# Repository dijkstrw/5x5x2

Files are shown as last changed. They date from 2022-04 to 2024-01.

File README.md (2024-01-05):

5x5x2 aka Orochi!
=================

This is a 5x5 Cherry mx matrix with hotswap Kailh sockets based my own
firmware for the STM32F1 with libopencm3. The project contains
firmware, schematics and a board layout in kicad.

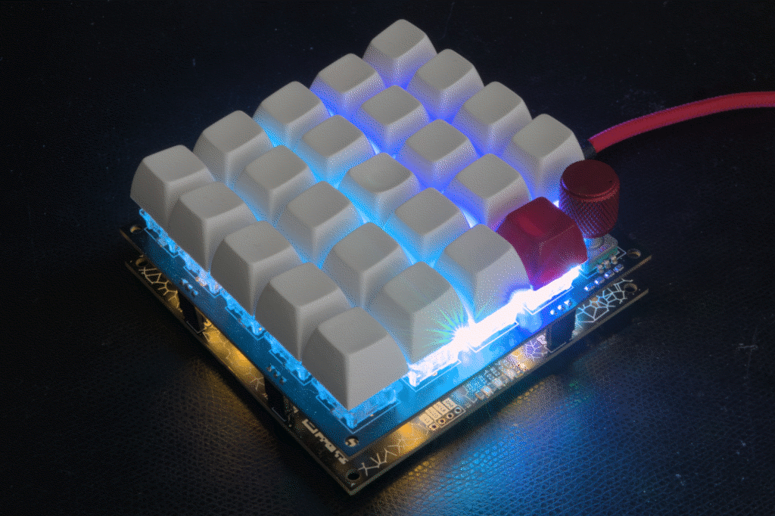
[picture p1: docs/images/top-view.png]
Board Front Picture


Features you expect given the above picture:
- bios boot and nkro keyboards, using usb keyboard scancodes
- system and consumer codes
- mouse events
- usb serial interface for configuration
- 8 sk68xx background leds on the bottom board
- 25 sk68xx underglow leds on the top board
- rotary encoder

Advanced features:
- adjustable speed macrokeys to e.g. emit passwords
- all leds individually addressable, colorchord support
- leds can light on e.g. volume or desktop changes
- configuration can be adjusted and flashed in userflash
- and an automouse that can simulate fast clicking

More pictures of the board and the development dongle are
[here](docs/IMAGES.md). If you want to build this yourself see
[building](docs/BUILDING.md). Interactive bom is
[here](https://glcdn.githack.com/dijkstrw/5x5x2/-/raw/30abe2597a5d5bfca67bad37a444652a956d1f03/schematic/bom/ibom.html).

Default firmware / my usecase
-----------------------------

This is my macropad; it contains three layers:

- X workspace layer, select workspace number, move about in VLC, start
  apps, compose key, quick jump to password layer and a number of app
  starting keys. Rotary dial controls system volume. Rotary press
  mutes/unmutes.

  Rgbleds show sound volume, current workspace / screen and active
  layer.

- numeric keypad, for when tkl is not enough

- macrokeys layer

Features
========

Keyboards
---------

The board provides 3 types of keyboards via different usb
endpoints.

1. The first is the usb standard bios keyboard definition, which
   allows the keyboard also to emit key codes to hosts with limited
   usb hid support. (This used to be the case in <2015 style bioses,
   hence the name.)

2. The second keyboard is a n-key-rollover, which exposes a keyboard
   that allows 224 usb keyboard scancodes to be pressed
   simultaneously. Also, because we do not need to adhere to the bios
   boot standard, this endpoint's interval can set much lower = it
   types much faster.

3. The third keyboard can emit so called consumer and system
   codes. Example consumer key codes are PLAY, PAUSE, but also MARK,
   CLEARMARK, REPEATFROMMARK. So everything the typical multimedia
   keys emit and then some.

Mouse
-----

Operate the rodent from your keyboard! There is support for x, y, 5
buttons and a vertical and horizontal scrollwheel action.

Serial
------

The board exposes a serial port for logging and
configuration. Configuration is done using commands, with these
general rules:

- Commands with lowercase letters request configuration information

- Commands with capital letters set configuration

- Arguments often are two hexadecimal digits long; e.g. ``00``,
  ``12``, ``fa``. If more digits are required, this is denoted in the
  argument specification by a colon, like so ``<argument:4>``.

The available commands are:

    ?  - show a terse description of available commands.

    i  - show usb info strings; contains the git-describe tag of the
         current firmware.

    d  - dump configuration of a named subsystem, see below.
    dg - dump the keymap light group
    dk - dump the keymap
    dp - dump the palette
    dr - dump the rotary configuration

    B  - set the bottom set of 8 leds (backlight) to custom rgb values.
         Takes a RGB argument of the form <rgb:6> times 8 for all leds.

    C  - set the top set of 25 leds (frontlight) to custom rgb values.
         Takes a RGB argument of the form <rgb:6> times 25 for all leds.

    D  - tell keyboard about an event that can be translated into a rgb
         light event, see below.
    DD - <screen><display> set current desktop display
    DM - <mute>            set sound output mute status
    DR - <mute>            set sound input/record mute
    DV - <volume:4>        set sound volume
         See config directory for a program that emits these events to the
         keyboard.

    G  - set light map for a key, takes argument of the form
         <layer><row><column><value>

    I  - set the rgb light intensity.

    K  - redefine a key in the keymap, takes argument of the form
         <layer><row><column><type><arg1><arg2><arg3>

    A  - clear all macro keys.

    M  - define one macro key, takes an argument of the form
         <number><oftenusedstring>. The number is a two hexdigits, the
         string can be upto 32 7-bit ascii chars long and is terminated
         with a newline.

    N  - set keyboard mode to <argument>; 00 for bios and 01 for nkro.
         Default is bios.

    P  - set palette color, takes arguments
         <number><hue:4><saturation><value>

    R  - redefine the rotary command, takes a argument of
         the form <layer><direction><type><arg1><arg2><arg3>

    L  - load configuration from flash

    S  - save configuration to flash

    Z  - clear the configration flash, revert to "factory" keymap at
         next powerup.

Command interpretation starts after receiving a newline.

Light events
------------

The keyboard will show desktop events as rgbled changes. This works in
a number of steps:

- There is a host program that connects to the serial port, monitors
  sound and workspace changes and communicates that back to the
  keyboard. The program can be found in
  [susanoo.py](config/susanoo.py). Note that workspace changes sent
  via a fifo using the desktop manager and
  [configuration](config/keys_orochi.lua).

- Incoming events are mapped to be shown on particular leds using the
  lightmap command.

- The events all have their own displays:

         B - backlight    - slow rainbow easing
         D - desktop      - desktop display mapped over palette
         L - layer        - layer mapped over palette
         m - macro        - if macro active, else backlight
         M - sound mute   - different colors for mute status
         V - volume       - volume mapped to color

Palette
-------

Colors in easings are assigned using a color index in the palette. The
default palette strives for a selection of colors that are visually
distinct from another.

The rotary action forward, backward and backlight colors have fixed
indexes, and can be set by adjusting their assigned palette colors.

Automouse
---------

Automouse is a mouse clicker, with optional speed setting and wiggle
amounts. This allows you to click real fast, and wiggle the mouse
while using your hands for something else.

Macros
------

Macros set via serial are lost at power off unless the configuration
is written to flash. Loading from flash happens automatically at
powerup.

The strings that you provide via serial need to be translated into usb
keycodes, so currently only 7-bit ascii strings are supported.

Setting macros via the shell is easy:

    echo -e "\nM01Nevergonnagiveyouup!\n" > /dev/ttyACM0

Or see [set_macro.sh](util/set_macro.sh).

Notes:

- The initial newline is a trick to make sure our M will be considered
  the start of a command, no matter what has been put to the serial
  before by you, some driver or the os.
- This particular example defines the macro for macro key number 1.
- You need to have a macro key 1 in your keymap, otherwise you have
  nothing to trigger the macro.
- There is intentionally no way to display stored macros.

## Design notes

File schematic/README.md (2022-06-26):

Other keyboard projects of interest:

- foostan: corne / crkb: the first time I saw sk6812 in mini-e
  variant. 
  
  https://github.com/foostan/kbd
  https://github.com/foostan/crkbd
  
  MIT license, parts reused:
  - Source of YS-SK6812-MINI-E schematic symbol, and 3d step model.

- KarlK90: Yaemk: indication that usb-c receptacle is usable without
  usb power negotiation.
  
  https://github.com/KarlK90/yaemk-split-kb
  
  GPLv3, used for inspiration only.

- Stefan Hamminga: sk6812mini model that models the underside of the
  package best.

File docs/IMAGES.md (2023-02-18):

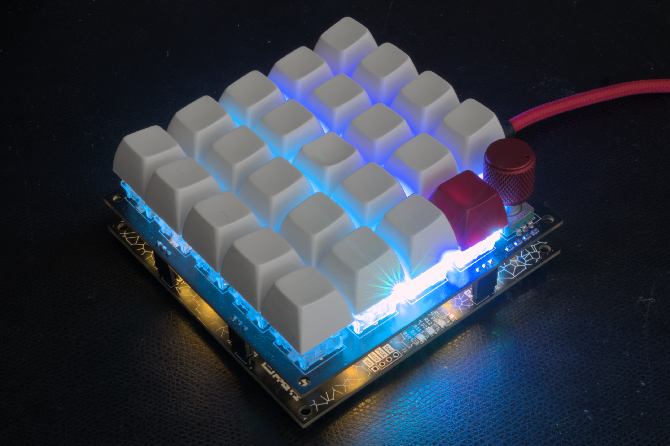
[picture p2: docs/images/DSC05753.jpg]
Orochi

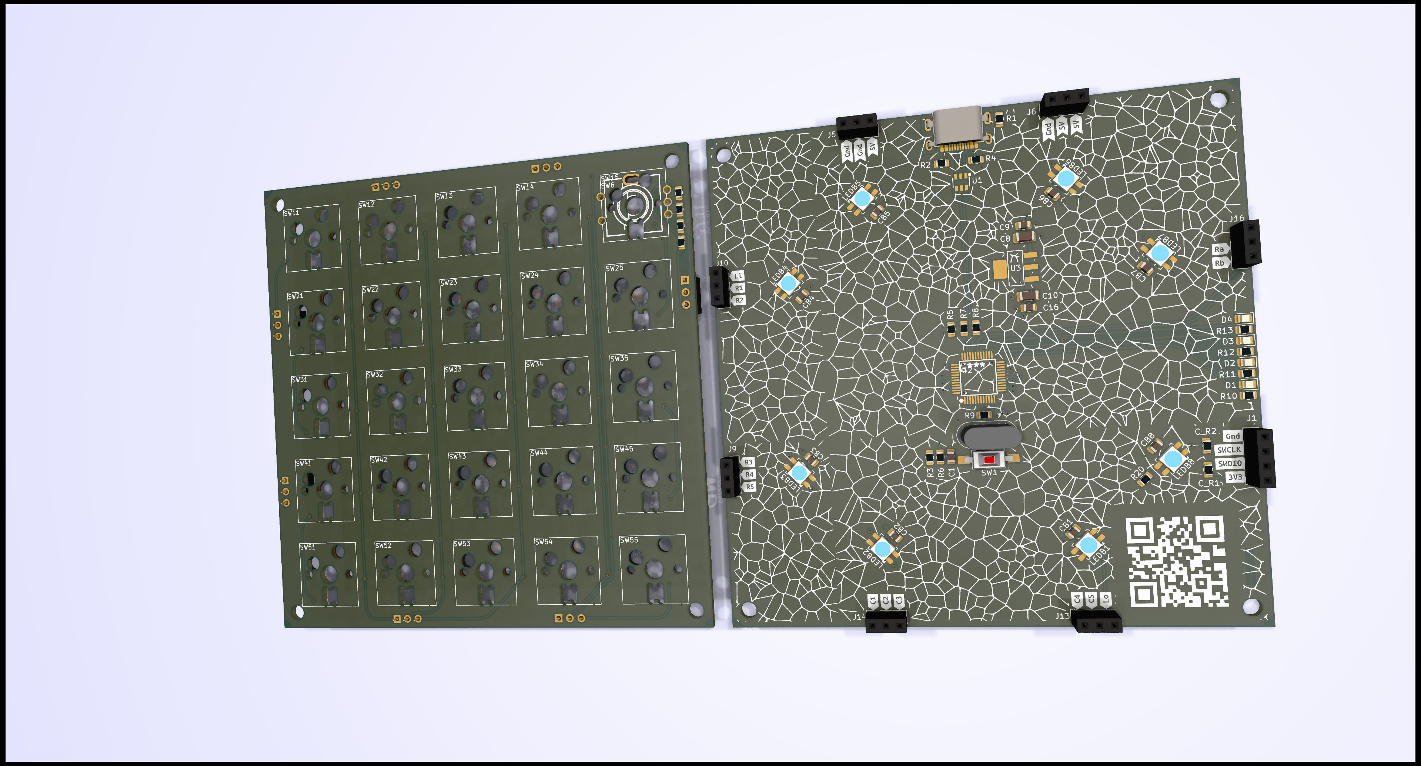
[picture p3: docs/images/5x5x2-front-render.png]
PCB front render

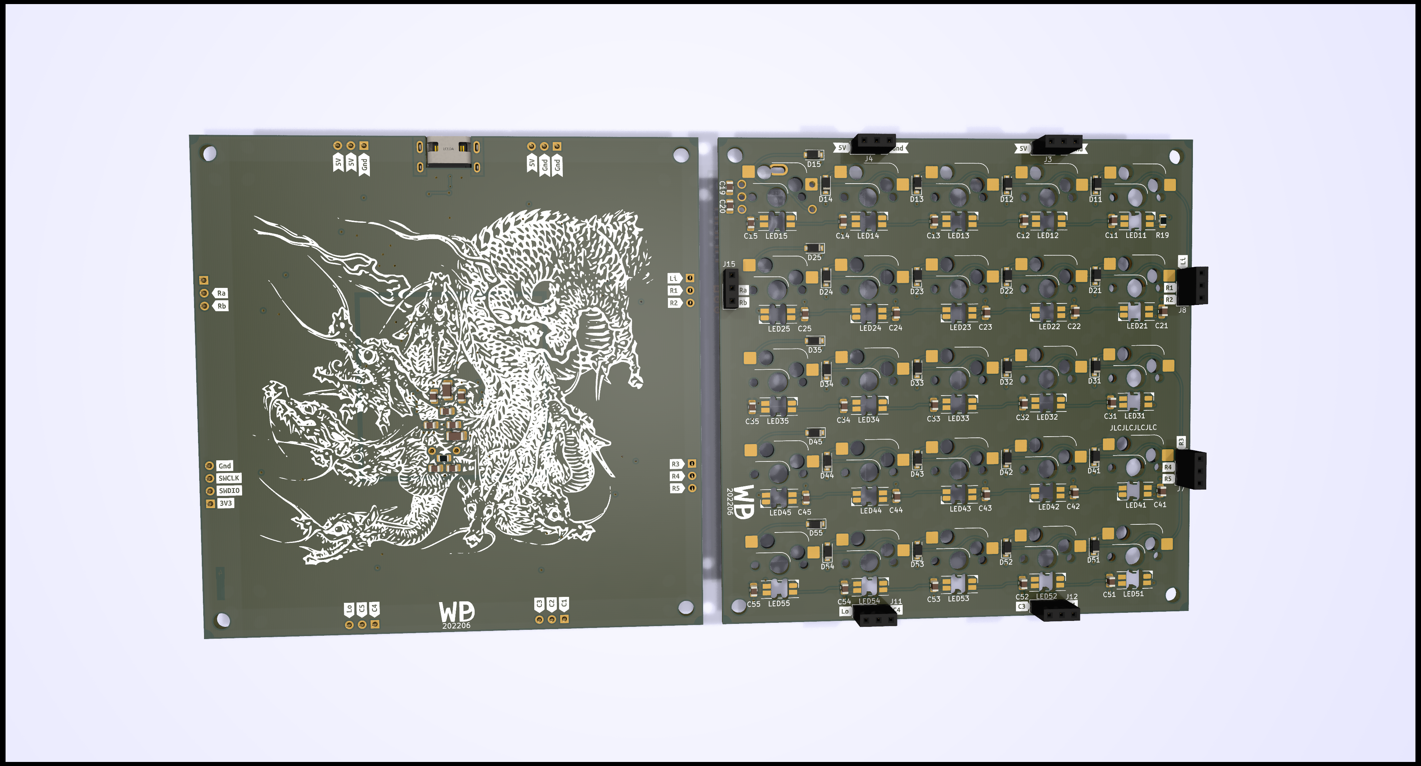
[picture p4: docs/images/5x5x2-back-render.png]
PCB back render

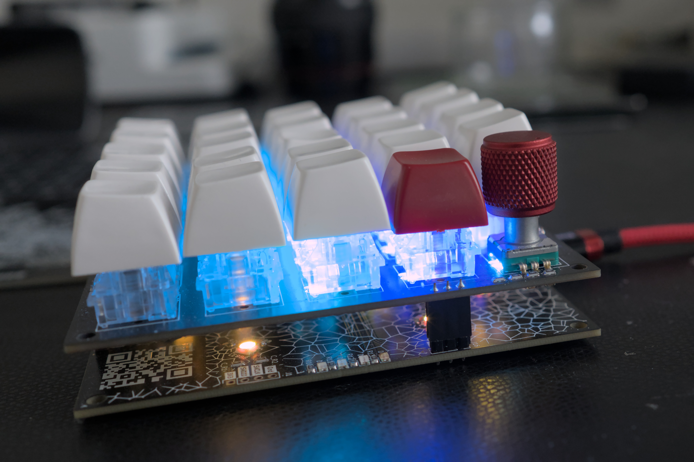
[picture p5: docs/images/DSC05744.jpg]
Side view

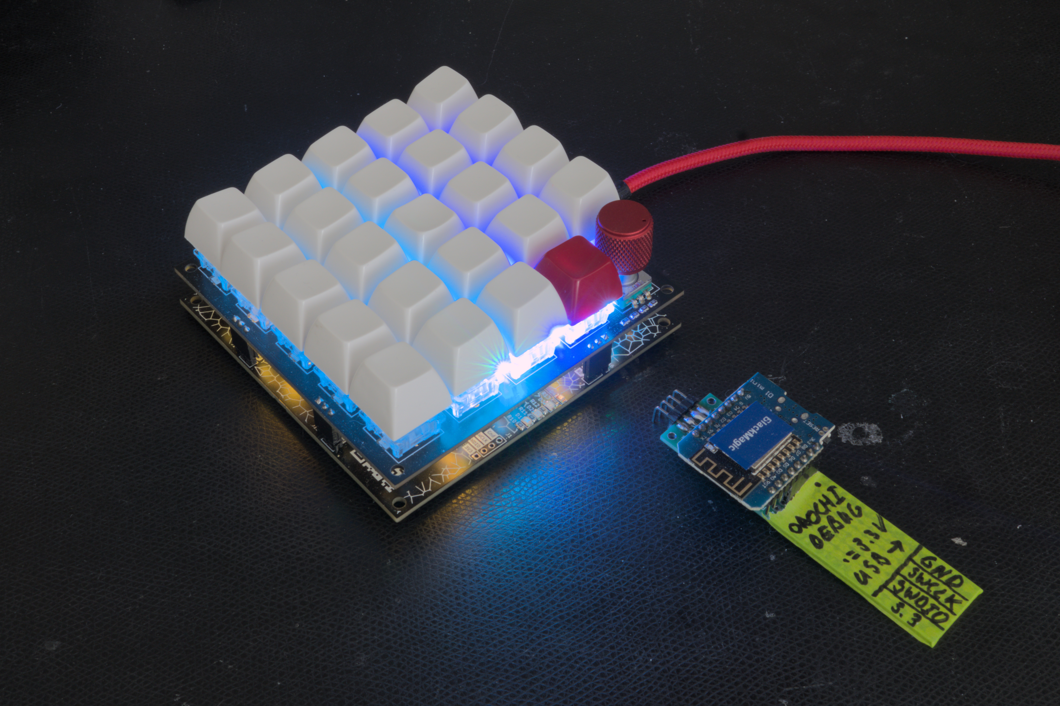
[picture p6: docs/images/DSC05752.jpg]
Development board


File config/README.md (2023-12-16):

Host configuration
==================

Orochi can be updated from the host using
[susanoo.py](susanoo.py). This program creates a fifo and a unix
domain socket that can be used to communicate with the keyboard.

- fifo: can be used by shell commands to push some state to the
  keyboard

- socket: can be used i.e. by socat, to communicate via terminal with
  the keyboard, even while multiple other updaters are active.

Susanoo also connects to pulseaudio to communicate volume and mute
status to the keyboard.

Desktop state (what desktop a screen is on) can be communicated using
[keys_orochi.lua](keys_orochi.lua), when using
[awesomewm](https://awesomewm.org/). This make it so that any desktop
key press on the keyboard will change all desktops for all connected
monitors. I like to use this to have a desktop for mail, a desktop for
a coding problem, and a few more for other side avenues that can pop
up while working on something. Desktop changes in awesome are
communicated back to the keyboard, and cause the keyboard two top rows
to light in the color of the active desktop.

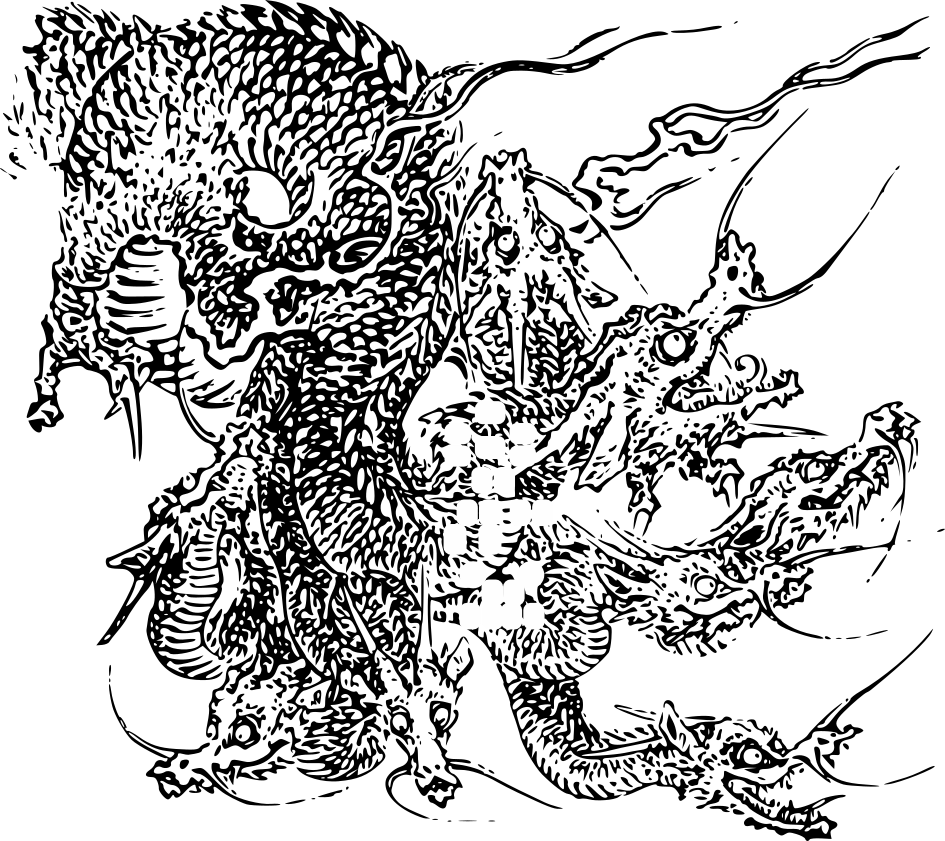
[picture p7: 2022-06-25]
schematic/images/orochi_board.png

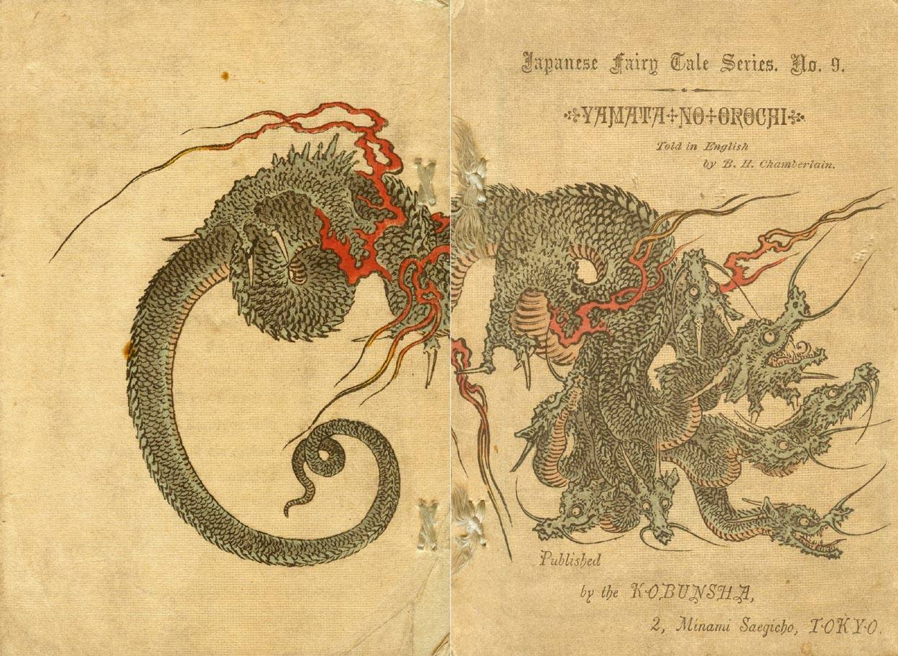
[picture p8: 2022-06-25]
schematic/images/orochi.jpg

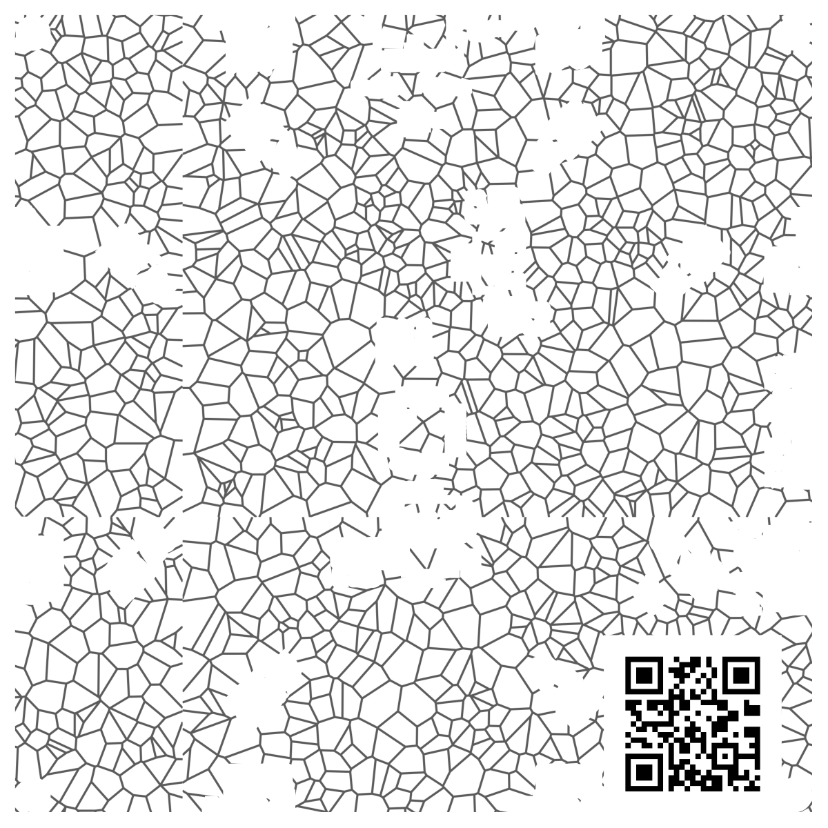
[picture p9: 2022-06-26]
schematic/images/sun.png

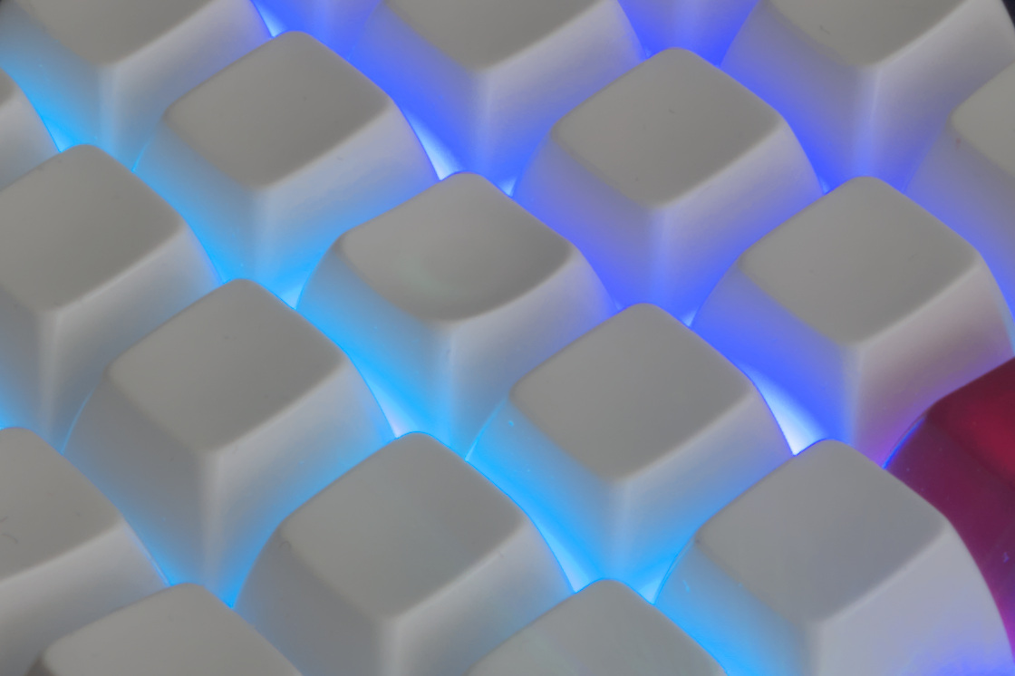
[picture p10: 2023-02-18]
docs/images/keys.jpg

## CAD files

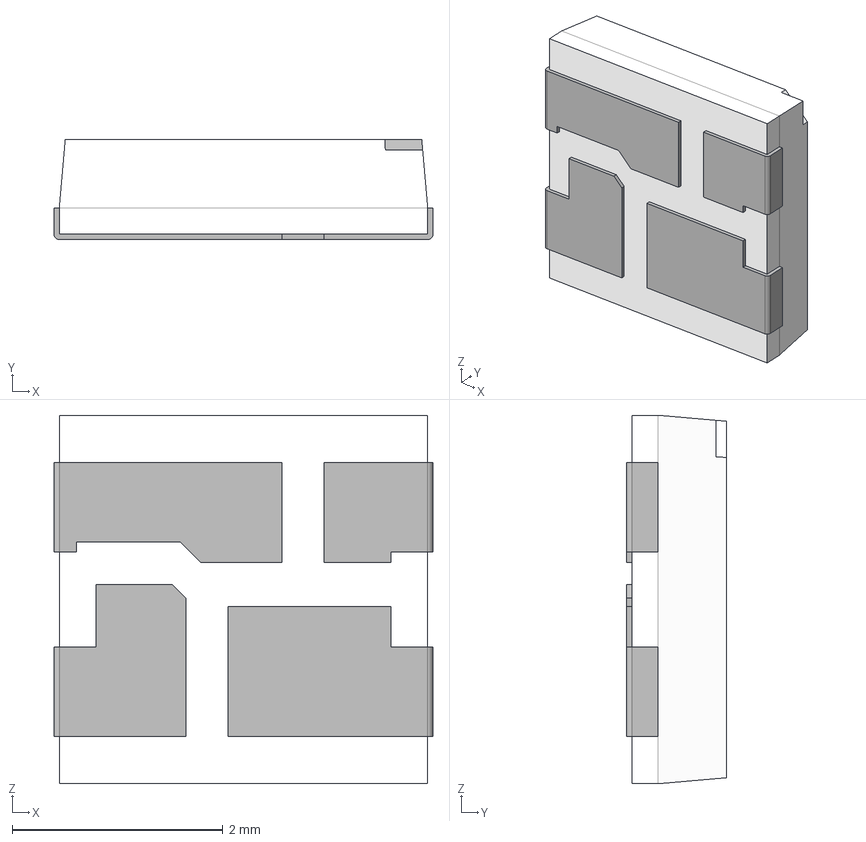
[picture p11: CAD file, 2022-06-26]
schematic/3dmodels/SK6812_Mini.step
3.60 x 0.95 x 3.50 mm
SK6812_Mini
SK6812_Mini004
SK6812_Mini003
SK6812_Mini005
SK6812_Mini002
SK6812_Mini001

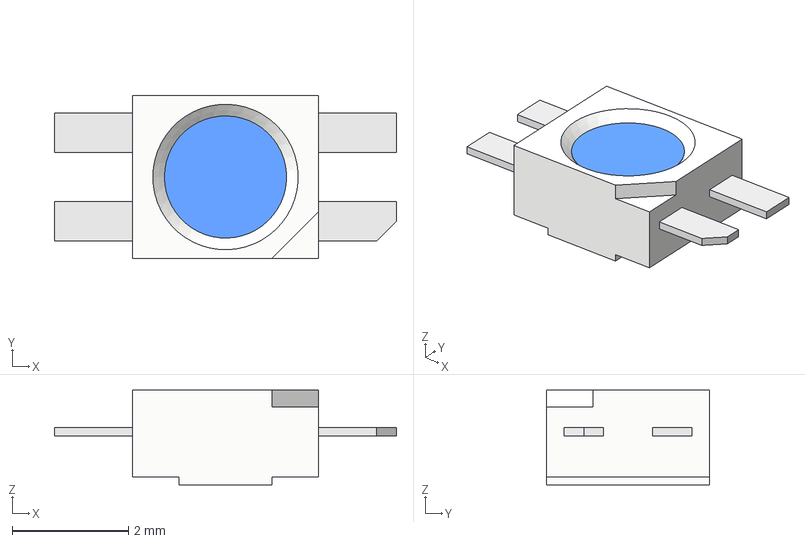
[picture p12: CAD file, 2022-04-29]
schematic/3dmodels/YS-SK6812MINI-E.step
5.88 x 2.80 x 1.63 mm

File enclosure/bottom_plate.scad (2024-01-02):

include <dimension.scad>;
include <plate.scad>;

if (PROJECTION) {
  projection(cut=true)
    bottom_plate();
 } else {
  bottom_plate();
 }

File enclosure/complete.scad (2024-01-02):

include <dimension.scad>;
include <plate.scad>;

bottom_plate();
translate([0, 0, bottom_height/2 + second_height/2]) second_plate();
translate([0, 0, bottom_height/2 + second_height + third_height/2]) third_plate();
translate([0, 0, bottom_height/2 + second_height + third_height]) top_plate();

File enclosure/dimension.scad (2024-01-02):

/*
 * Dimension of the boards as a stack:
 *
 *      mx switch stem     +                     3.6 mm
 *      mx switch top    ╭---╮                   6.6 mm
 *      mx switch foot   |   |                   5.0 mm -╮
 *             top pcb ╦═╪═══╪═══════════════╦   1.6 mm  |
 *                     ║                     ║   5.9 mm  | 15.1 mm
 *           lower pcb ╩═╪═════════════════╪═╩   1.6 mm  |
 *      solder fillets                           1.0 mm -╯
 *
 * The enclosure must enclose the pcb (100 x 100) and vertically from
 * the lower pcb solder fillets upto the mx switch foot. This is a
 * 15.1 mm span. To fixate the switches the top will be closed by a
 * metal plate with mx sized (13.8 x 13.8) holes in it. The plate is
 * 1.6mm thick, so the total vertical span to cover with the enclosure
 * material is 15.1 - 1.6 = 13.5 mm.
 *
 * The lower pcb has an usb c receptable, so room must be left for the
 * usb plug and overmoulding.
 *
 * PMMA layers can be bought in a variety of thicknesses, but we must
 * take care that in our stack-up the PMMA layer is supported by the
 * top or lower pcb to stay in place. This means that layer
 * transitions can only happen between 1.2 - 2.4 mm or 6.1 - 7.3 mm.
 *
 * Our 3mm screw inserts are 4.9mm high, so even with a 3mm baseplate,
 * our lower pcb will only start from 4.9mm -- this does mean that the
 * usb receptacle is at 4.9 + 0.8, and with usb overmoulding needing
 * 6.8mm, we need:
 *
 * - second layer = 1.9 screw insert +
 *                  0.8 middle of pcb +
 *                  6.8 / 2 usb plug size = 6.1mm
 * - third layer = 13.5 - 6.1             = 7.4mm
 *
 */

pcb_width = 100;             // width and depth of pcb to enclose
pcb_thickness = 1.6;         // thickness of the pcb
pcb_fillets = 1;             // max size of the fillets under pcb

wall_width = 3;              // width of the wall around the enclosure
screw_insert_size = 4.9;     // height of screw inserts

bottom_height = 3;           // height of bottom plate
second_height = 6.1;         // height of second plate
third_height = 13.5 - second_height;
top_height = 1.6;            // height of keys base plate

screw_hole_size = 3;         // hole size, m3 = 3mm
hole_offset = 3.5;           // offset of hole center to edge

usb_plug_height = 6.8;       // height of usb c plug overmoulding
usb_plug_width = 11;         // width of usb c plug overmoulding
usb_plug_depth = 24.3;       // depth of usb c plug, contact + overmoulding
usb_contact_height = 3;      // height of usb c contact

mx_plate_width = 13.8;
mx_edge_space = 5.5;
mx_inter_space = 5;

$fn = 50;                    // number of fragments in an arc

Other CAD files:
enclosure/plate.scad
enclosure/second_plate.scad
enclosure/third_plate.scad
enclosure/top_plate.scad

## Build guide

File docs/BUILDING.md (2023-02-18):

Building
========

The repo comes with a number of goodies to make developer life more
fun:

- docker definition for required toolchain
- docker/dev.sh to quickly and seamlessly issue commands in the toolchain container
- gdb-regview and .gdbinit to load pheriperal names into gdb
- use of blackmagic esp8266 to flash firmware via wifi

How to build the firmware
-------------------------

    git clone --recursive 5x5x2.git
    cd 5x5x2/docker
    docker build -t stm32-gcc .
    cd ..
    ./docker/dev.sh "make -C libopencm3 && make"

How to debug the firmware
-------------------------

I use an [esp8266](https://github.com/walmis/blackmagic-espidf)
programmed as a
[blackmagic](https://github.com/blacksphere/blackmagic) probe to
connect gdb via wifi to the target keyboard. The board has a 4-pin
SWIO/SWCLK .1'' header on the right lower side where the probe can be
attached.

```console
[dijkstra@mcu 5x5x2]$ ./docker/dev.sh 
root@df176a49d098:/mnt# make debug 
arm-none-eabi-gdb-py --command=.gdb_config
GNU gdb (GNU Arm Embedded Toolchain 10-2020-q4-major) 10.1.90.20201028-git
Copyright (C) 2020 Free Software Foundation, Inc.
License GPLv3+: GNU GPL version 3 or later <http://gnu.org/licenses/gpl.html>
This is free software: you are free to change and redistribute it.
There is NO WARRANTY, to the extent permitted by law.
Type "show copying" and "show warranty" for details.
This GDB was configured as "--host=x86_64-linux-gnu --target=arm-none-eabi".
Type "show configuration" for configuration details.
For bug reporting instructions, please see:
<https://www.gnu.org/software/gdb/bugs/>.
Find the GDB manual and other documentation resources online at:
    <http://www.gnu.org/software/gdb/documentation/>.

For help, type "help".
Type "apropos word" to search for commands related to "word".
spi_disable_tx_dma (spi=1073819648) at ../common/spi_common_all.c:674
674		SPI_CR2(spi) &= ~SPI_CR2_TXDMAEN;
Black Magic Probeesp8266v1.7.1-252-g863a41d, Hardware Version 0
Copyright (C) 2015  Black Sphere Technologies Ltd.
License GPLv3+: GNU GPL version 3 or later <http://gnu.org/licenses/gpl.html>

Target voltage: 2965mV
Available Targets:
No. Att Driver
 1      STM32F1 medium density M3
A program is being debugged already.  Kill it? (y or n) [answered Y; input not from terminal]
[Switching to Thread 1]
0x0800218e in col_read () at matrix.c:85
85	{
Breakpoint 1 at 0x80001d2: file 5x5x2.c, line 81.
Note: automatically using hardware breakpoints for read-only addresses.
Loaded gdb-regview/gdb-regview.py
Type "regview <tab>" to see available commands.
Loaded register definitions: gdb-regview/defs/STM32F10X_CL.xml
```
```gdb
(gdb) load 5x5x2.elf 
Loading section .text, size 0x84a4 lma 0x8000000
Loading section .data, size 0x4a4 lma 0x80084a4
Loading section .userflash, size 0x1000 lma 0x800f000
Start address 0x08006f38, load size 39240
Transfer rate: 4 KB/sec, 934 bytes/write.
(gdb) r
The program being debugged has been started already.
Start it from the beginning? (y or n) y
Starting program: /mnt/5x5x2.elf 
[Switching to Thread 1]

Breakpoint 1, main () at 5x5x2.c:81
81	    mcu_init();
(gdb) 
```

Example use of [regview](https://github.com/fnoble/gdb-regview):
```gdb
(gdb) regview show SPI1_CR1 
SPI1_CR1 (*0x40013000) = 0x00000000

CPHA	0x0		Clock Phase
CPOL	0x0		Clock Polarity
MSTR	0x0		Master Selection
BR	0x0		BR[2:0] bits (Baud Rate Control)
SPE	0x0		SPI Enable
LSBFIRST	0x0		Frame Format
SSI	0x0		Internal slave select
SSM	0x0		Software slave management
RXONLY	0x0		Receive only
DFF	0x0		Data Frame Format
CRCNEXT	0x0		Transmit CRC next
CRCEN	0x0		Hardware CRC calculation enable
BIDIOE	0x0		Output enable in bidirectional mode
BIDIMODE	0x0		Bidirectional data mode enable
(gdb) 
```

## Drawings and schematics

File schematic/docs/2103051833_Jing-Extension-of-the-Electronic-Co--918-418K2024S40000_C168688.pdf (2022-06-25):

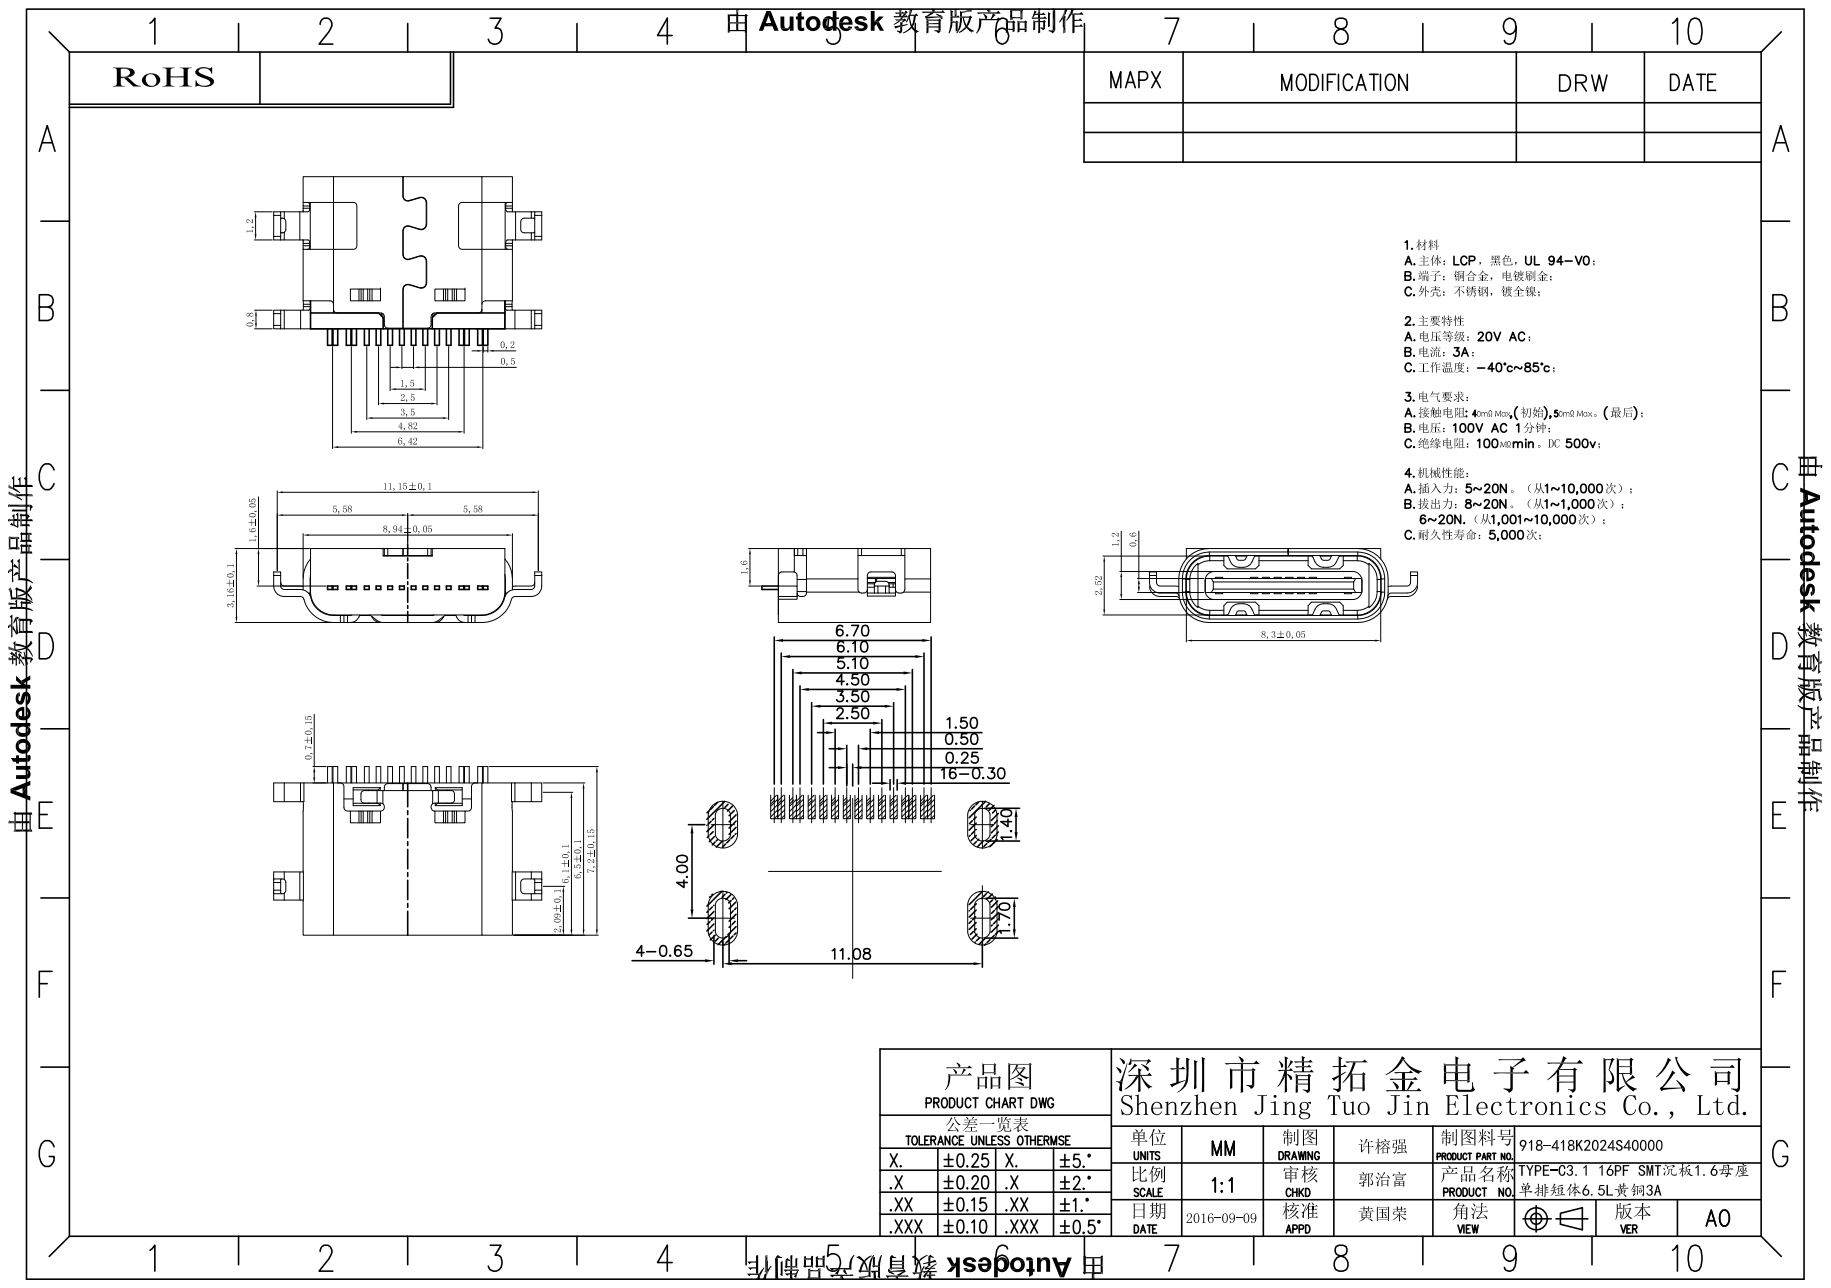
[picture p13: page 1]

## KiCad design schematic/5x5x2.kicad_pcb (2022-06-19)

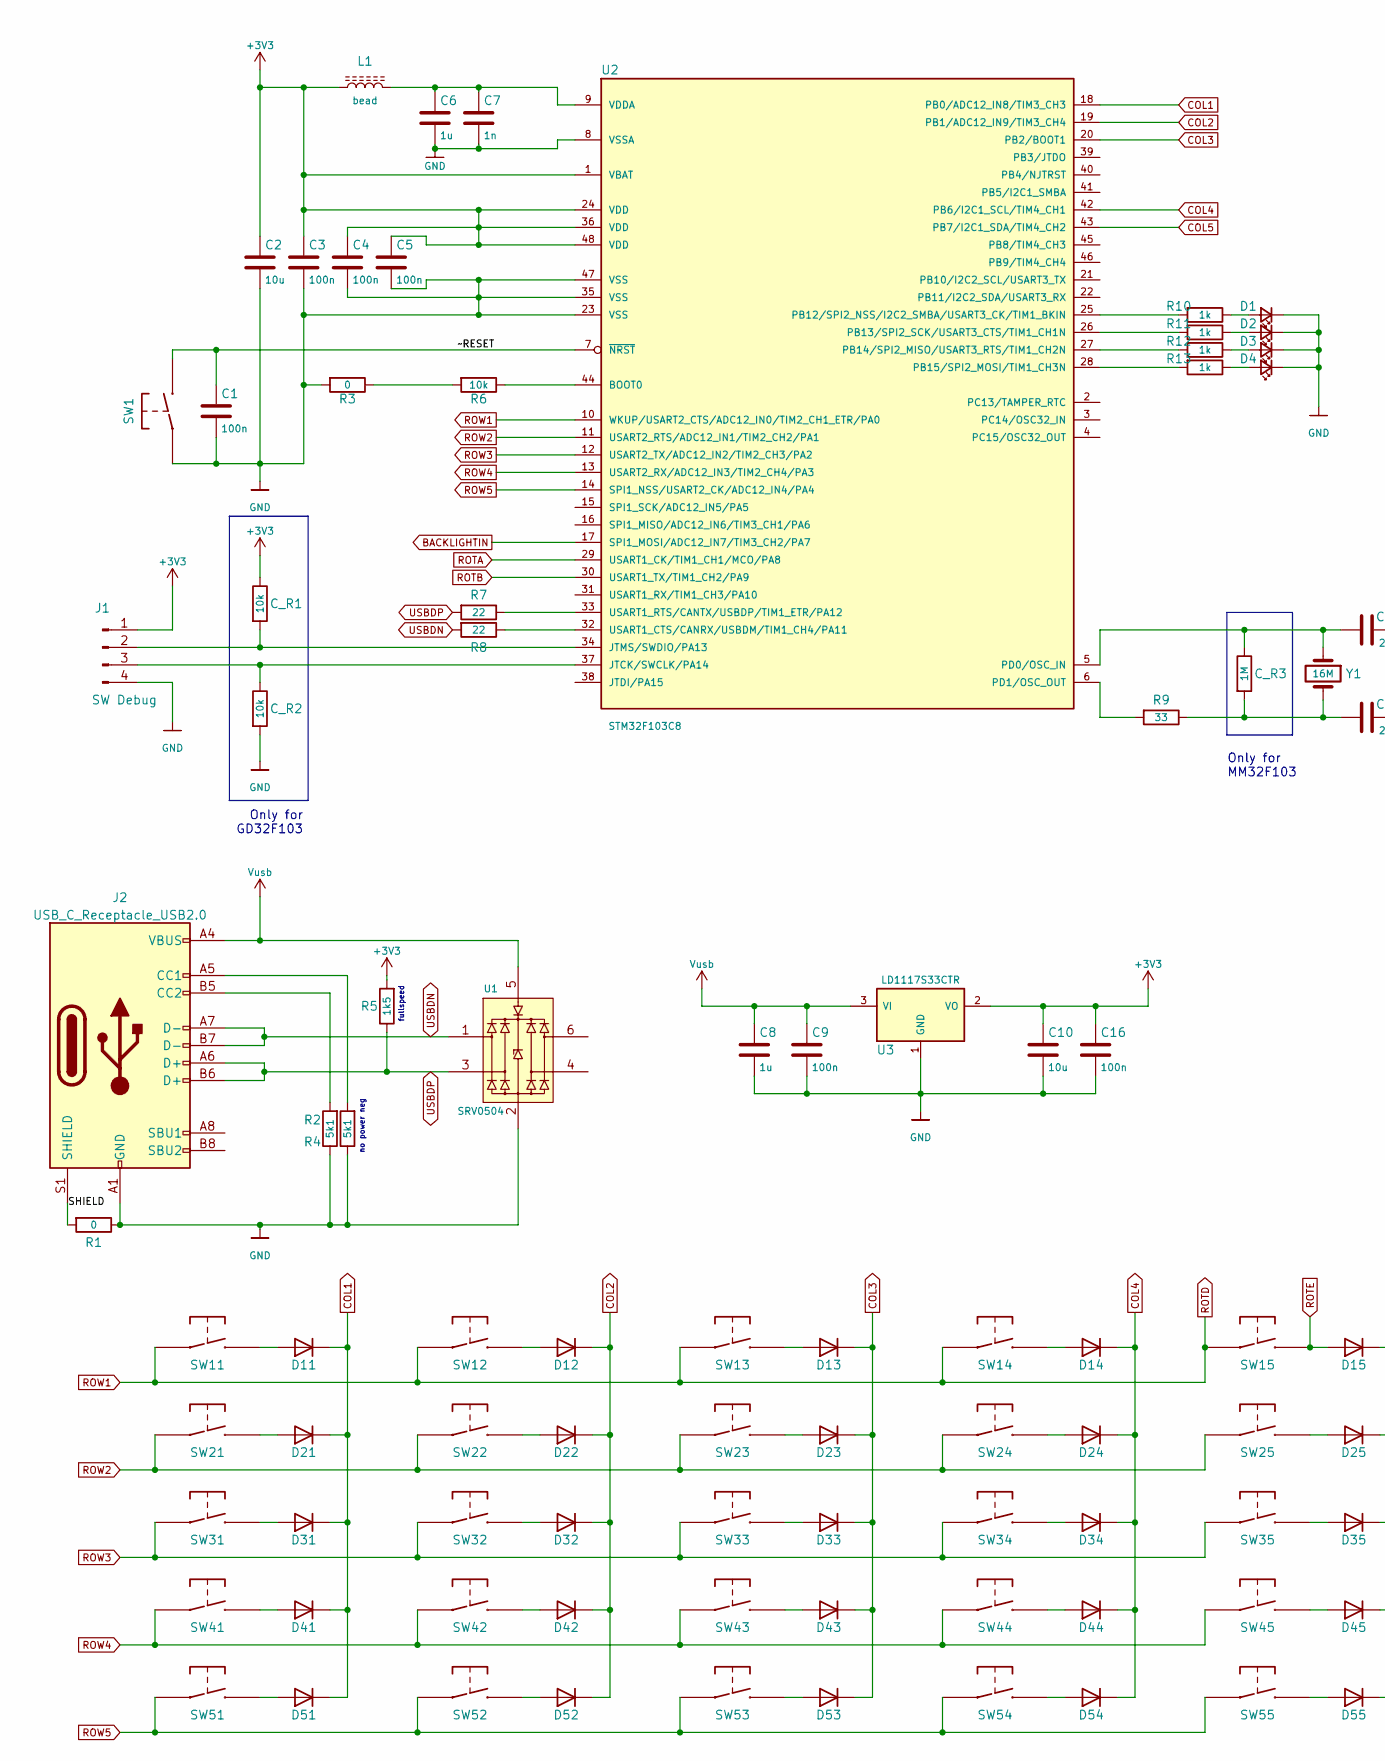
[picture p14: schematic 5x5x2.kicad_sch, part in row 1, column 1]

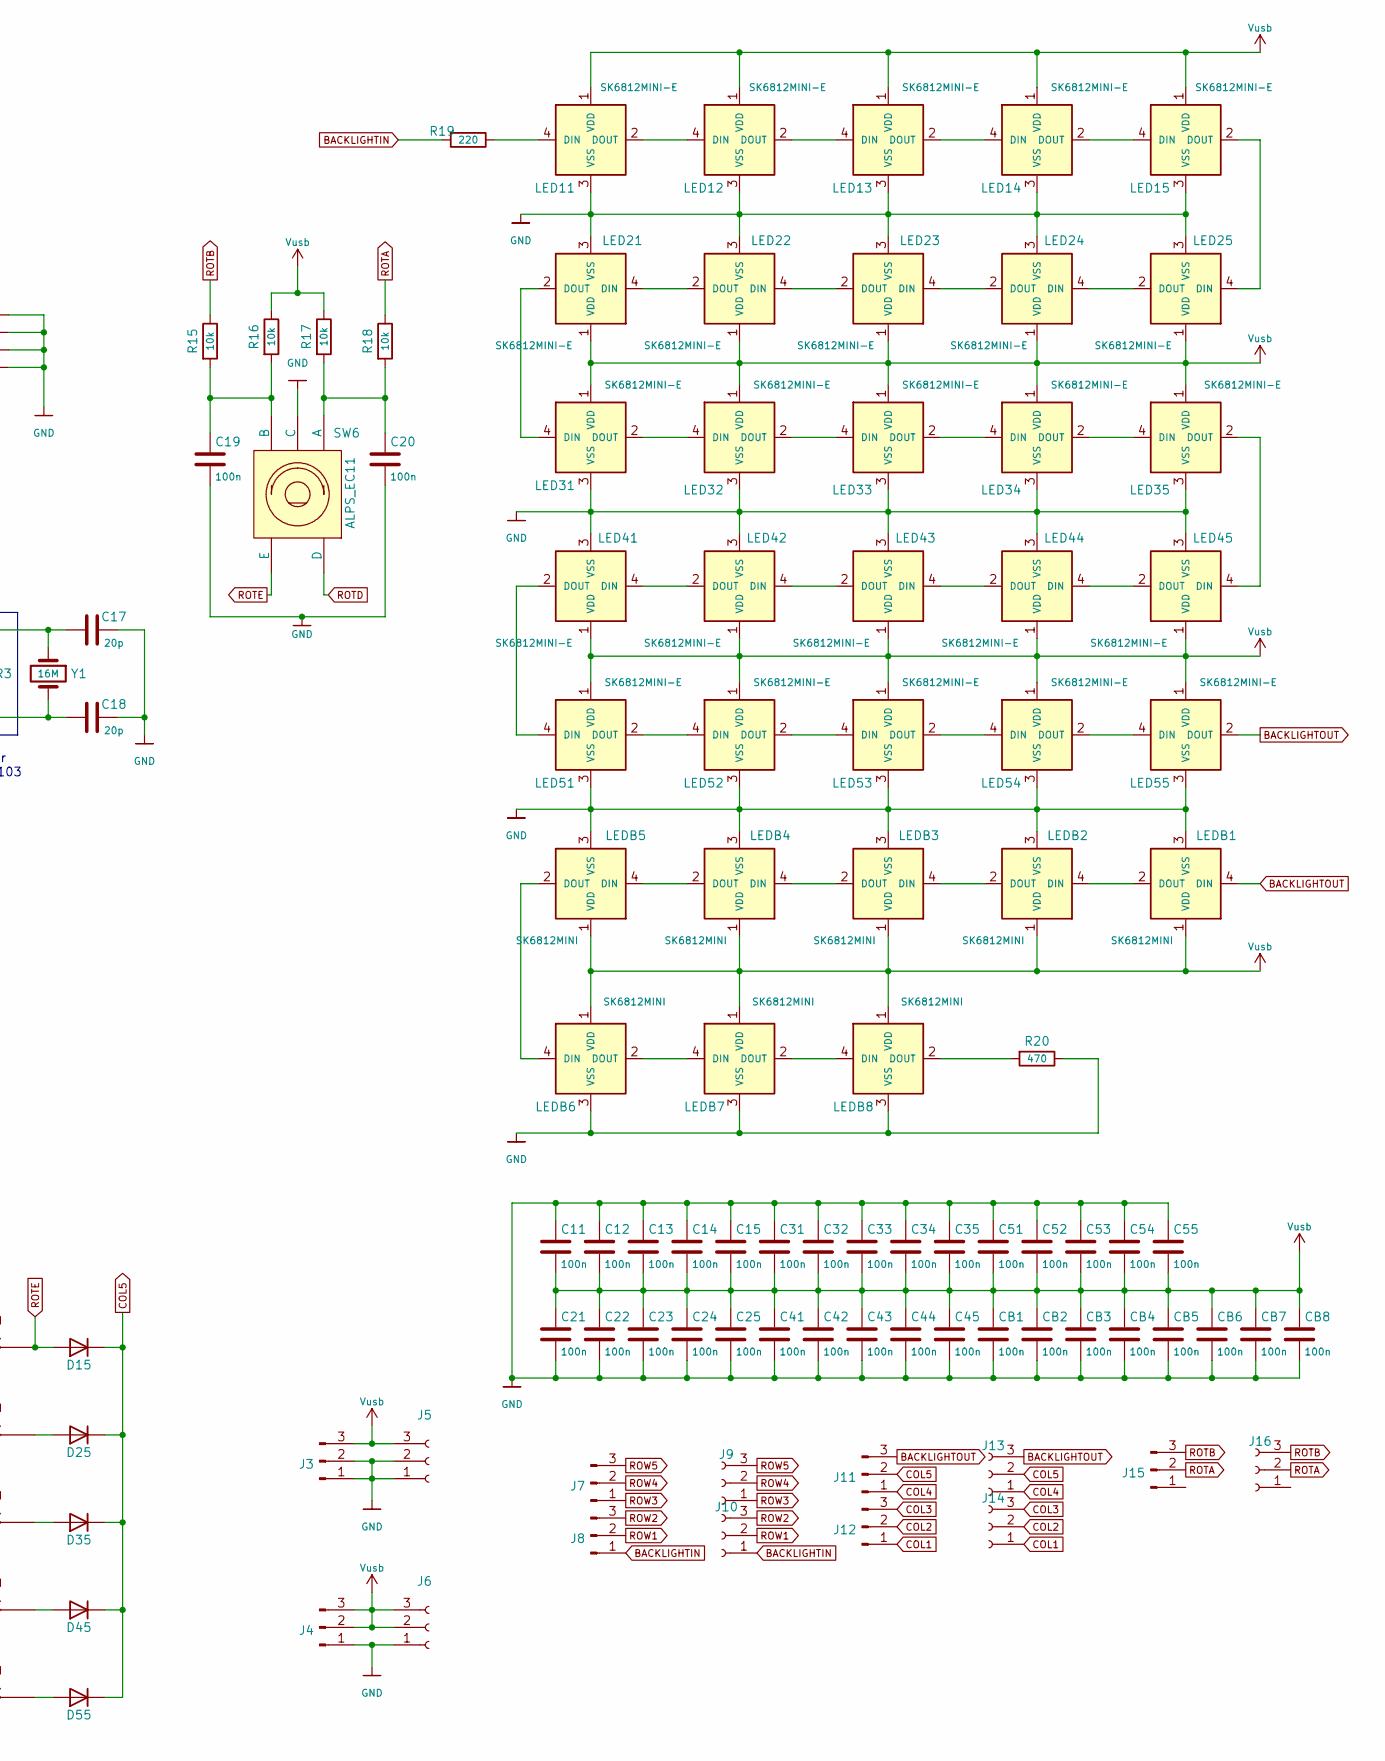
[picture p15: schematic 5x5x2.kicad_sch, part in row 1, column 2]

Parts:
C1, C3, C4, C5, C9, C11, C12, C13, C14, C15, C16, C19, C20, C21, C22, C23, C24, C25, C31, C32, C33, C34, C35, C41, C42, C43, C44, C45, C51, C52, C53, C54, C55: 100n; C_0805_2012Metric
C2, C10: 10u; C_1206_3216Metric
C6, C8: 1u; C_1206_3216Metric
C7: 1n; C_0805_2012Metric
C17, C18: 20p; C_0805_2012Metric
CB1, CB2, CB3, CB4, CB5, CB6, CB7, CB8: 100n; C_0805_2012Metric
C_R1, C_R2: 10k; R_0805_2012Metric
C_R3: 1M; R_0805_2012Metric
D1, D2, D3, D4: Led_Small; LED_0805_2012Metric
D11, D12, D13, D14, D15, D21, D22, D23, D24, D25, D31, D32, D33, D34, D35, D41, D42, D43, D44, D45, D51, D52, D53, D54, D55: 1N4148; D_SOD-123F
J1: SW Debug; PinSocket_1x04_P2.54mm_Vertical
J2: USB_C_Receptacle_USB2.0; USB-C-SMD_TYPE-C-USB-4
J3, J4, J7, J8, J11, J12, J15: Conn_01x03_Male; PinSocket_1x03_P2.54mm_Vertical
J5, J6, J9, J10, J13, J14, J16: Conn_01x03_Female; PinSocket_1x03_P2.54mm_Vertical
L1: bead; C_0805_2012Metric
LED11, LED12, LED13, LED14, LED15, LED21, LED22, LED23, LED24, LED25, LED31, LED32, LED33, LED34, LED35, LED41, LED42, LED43, LED44, LED45, LED51, LED52, LED53, LED54, LED55: SK6812MINI-E; YS-SK6812MINI-E
LEDB1, LEDB2, LEDB3, LEDB4, LEDB5, LEDB6, LEDB7, LEDB8: SK6812MINI; SK6812MINI_rev
R1, R3: 0; R_0805_2012Metric
R2, R4: 5k1; R_0805_2012Metric
R5: 1k5; R_0805_2012Metric
R6, R15, R16, R17, R18: 10k; R_0805_2012Metric
R7, R8: 22; R_0805_2012Metric
R9: 33; R_0805_2012Metric
R10, R11, R12, R13: 1k; R_0805_2012Metric
R19: 220; R_0805_2012Metric
R20: 470; R_0805_2012Metric
SW1: SW; SW_SPST_FSMSM
SW6: ALPS_EC11; SW-TH_EC11XXXXXXXX
SW11, SW12, SW13, SW14, SW15, SW21, SW22, SW23, SW24, SW25, SW31, SW32, SW33, SW34, SW35, SW41, SW42, SW43, SW44, SW45, SW51, SW52, SW53, SW54, SW55: SW; SW_Hotswap_Kailh_MX_1.00u
U1: SRV0504; SOT-23-6_L2.9-W1.6-P0.95-LS2.8-BL
U2: STM32F103C8; LQFP-48_L7.0-W7.0-P0.50-LS9.0-BL
U3: LD1117S33CTR; SOT-223-4_L6.5-W3.5-P2.30-LS7.0-BR
Y1: 16M; Crystal_HC49-U_Vertical

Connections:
+3V3: C2.1, C3.1, C4.1, C5.1, C10.1, C16.1, C_R1.1, J1.1, L1.1, R5.2, U2.1 (VBAT), U2.24 (VDD), U2.36 (VDD), U2.48 (VDD), U3.2 (VO)
/SHIELD: J2.S1 (SHIELD), R1.2
/~RESET: C1.1, SW1.2, U2.7 (~NRST)
BACKLIGHTIN: J8.1, J10.1, R19.2, U2.17 (SPI1_MOSI/ADC12_IN7/TIM3_CH2/PA7)
BACKLIGHTOUT: J11.3, J13.3, LED55.2 (DOUT), LEDB1.4 (DIN)
COL1: D11.1 (K), D21.1 (K), D31.1 (K), D41.1 (K), D51.1 (K), J12.1, J14.1, U2.18 (PB0/ADC12_IN8/TIM3_CH3)
COL2: D12.1 (K), D22.1 (K), D32.1 (K), D42.1 (K), D52.1 (K), J12.2, J14.2, U2.19 (PB1/ADC12_IN9/TIM3_CH4)
COL3: D13.1 (K), D23.1 (K), D33.1 (K), D43.1 (K), D53.1 (K), J12.3, J14.3, U2.20 (PB2/BOOT1)
COL4: D14.1 (K), D24.1 (K), D34.1 (K), D44.1 (K), D54.1 (K), J11.1, J13.1, U2.42 (PB6/I2C1_SCL/TIM4_CH1)
COL5: D15.1 (K), D25.1 (K), D35.1 (K), D45.1 (K), D55.1 (K), J11.2, J13.2, U2.43 (PB7/I2C1_SDA/TIM4_CH2)
GND: C1.2, C2.2, C3.2, C4.2, C5.2, C6.2, C7.2, C8.2, C9.2, C10.2, C11.1, C12.1, C13.1, C14.1, C15.1, C16.2, C17.1, C18.1, C19.2, C20.2, C21.2, C22.2, C23.2, C24.2, C25.2, C31.1, C32.1, C33.1, C34.1, C35.1, C41.2, C42.2, C43.2, C44.2, C45.2, C51.1, C52.1, C53.1, C54.1, C55.1, CB1.2, CB2.2, CB3.2, CB4.2, CB5.2, CB6.2, CB7.2, CB8.2, C_R2.2, D1.1 (K), D2.1 (K), D3.1 (K), D4.1 (K), J1.4, J2.A1 (GND), J2.A12 (GND), J2.B1 (GND), J2.B12 (GND), J3.1, J3.2, J4.1, J5.1, J5.2, J6.1, LED11.3 (VSS), LED12.3 (VSS), LED13.3 (VSS), LED14.3 (VSS), LED15.3 (VSS), LED21.3 (VSS), LED22.3 (VSS), LED23.3 (VSS), LED24.3 (VSS), LED25.3 (VSS), LED31.3 (VSS), LED32.3 (VSS), LED33.3 (VSS), LED34.3 (VSS), LED35.3 (VSS), LED41.3 (VSS), LED42.3 (VSS), LED43.3 (VSS), LED44.3 (VSS), LED45.3 (VSS), LED51.3 (VSS), LED52.3 (VSS), LED53.3 (VSS), LED54.3 (VSS), LED55.3 (VSS), LEDB1.3 (VSS), LEDB2.3 (VSS), LEDB3.3 (VSS), LEDB4.3 (VSS), LEDB5.3 (VSS), LEDB6.3 (VSS), LEDB7.3 (VSS), LEDB8.3 (VSS), R1.1, R2.1, R3.2, R4.1, R20.1, SW1.1, SW6.C, U1.2 (GND), U2.8 (VSSA), U2.23 (VSS), U2.35 (VSS), U2.47 (VSS), U3.1 (GND)
unnamed: C6.1, C7.1, L1.2, U2.9 (VDDA)
unnamed: C17.2, C_R3.1, U2.5 (PD0/OSC_IN), Y1.1
unnamed: C18.2, C_R3.2, R9.1, Y1.2
unnamed: C19.1, R15.2, R16.2, SW6.B
unnamed: C20.1, R17.2, R18.2, SW6.A
unnamed: C_R1.2, J1.2, U2.34 (JTMS/SWDIO/PA13)
unnamed: C_R2.1, J1.3, U2.37 (JTCK/SWCLK/PA14)
unnamed: D1.2 (A), R10.1
unnamed: D2.2 (A), R11.1
unnamed: D3.2 (A), R12.1
unnamed: D4.2 (A), R13.1
unnamed: D11.2 (A), SW11.2
unnamed: D12.2 (A), SW12.2
unnamed: D13.2 (A), SW13.2
unnamed: D14.2 (A), SW14.2
unnamed: D21.2 (A), SW21.2
unnamed: D22.2 (A), SW22.2
unnamed: D23.2 (A), SW23.2
unnamed: D24.2 (A), SW24.2
unnamed: D25.2 (A), SW25.2
unnamed: D31.2 (A), SW31.2
unnamed: D32.2 (A), SW32.2
unnamed: D33.2 (A), SW33.2
unnamed: D34.2 (A), SW34.2
unnamed: D35.2 (A), SW35.2
unnamed: D41.2 (A), SW41.2
unnamed: D42.2 (A), SW42.2
unnamed: D43.2 (A), SW43.2
unnamed: D44.2 (A), SW44.2
unnamed: D45.2 (A), SW45.2
unnamed: D51.2 (A), SW51.2
unnamed: D52.2 (A), SW52.2
unnamed: D53.2 (A), SW53.2
unnamed: D54.2 (A), SW54.2
unnamed: D55.2 (A), SW55.2
unnamed: J2.A5 (CC1), R4.2
unnamed: J2.B5 (CC2), R2.2
unnamed: LED11.2 (DOUT), LED12.4 (DIN)
unnamed: LED11.4 (DIN), R19.1
unnamed: LED12.2 (DOUT), LED13.4 (DIN)
unnamed: LED13.2 (DOUT), LED14.4 (DIN)
unnamed: LED14.2 (DOUT), LED15.4 (DIN)
unnamed: LED15.2 (DOUT), LED25.4 (DIN)
unnamed: LED21.2 (DOUT), LED31.4 (DIN)
unnamed: LED21.4 (DIN), LED22.2 (DOUT)
unnamed: LED22.4 (DIN), LED23.2 (DOUT)
unnamed: LED23.4 (DIN), LED24.2 (DOUT)
unnamed: LED24.4 (DIN), LED25.2 (DOUT)
unnamed: LED31.2 (DOUT), LED32.4 (DIN)
unnamed: LED32.2 (DOUT), LED33.4 (DIN)
unnamed: LED33.2 (DOUT), LED34.4 (DIN)
unnamed: LED34.2 (DOUT), LED35.4 (DIN)
unnamed: LED35.2 (DOUT), LED45.4 (DIN)
unnamed: LED41.2 (DOUT), LED51.4 (DIN)
unnamed: LED41.4 (DIN), LED42.2 (DOUT)
unnamed: LED42.4 (DIN), LED43.2 (DOUT)
unnamed: LED43.4 (DIN), LED44.2 (DOUT)
unnamed: LED44.4 (DIN), LED45.2 (DOUT)
unnamed: LED51.2 (DOUT), LED52.4 (DIN)
unnamed: LED52.2 (DOUT), LED53.4 (DIN)
unnamed: LED53.2 (DOUT), LED54.4 (DIN)
unnamed: LED54.2 (DOUT), LED55.4 (DIN)
unnamed: LEDB1.2 (DOUT), LEDB2.4 (DIN)
unnamed: LEDB2.2 (DOUT), LEDB3.4 (DIN)
unnamed: LEDB3.2 (DOUT), LEDB4.4 (DIN)
unnamed: LEDB4.2 (DOUT), LEDB5.4 (DIN)
unnamed: LEDB5.2 (DOUT), LEDB6.4 (DIN)
unnamed: LEDB6.2 (DOUT), LEDB7.4 (DIN)
unnamed: LEDB7.2 (DOUT), LEDB8.4 (DIN)
unnamed: LEDB8.2 (DOUT), R20.2
unnamed: R3.1, R6.2
unnamed: R6.1, U2.44 (BOOT0)
unnamed: R7.1, U2.33 (USART1_RTS/CANTX/USBDP/TIM1_ETR/PA12)
unnamed: R8.1, U2.32 (USART1_CTS/CANRX/USBDM/TIM1_CH4/PA11)
unnamed: R9.2, U2.6 (PD1/OSC_OUT)
unnamed: R10.2, U2.25 (PB12/SPI2_NSS/I2C2_SMBA/USART3_CK/TIM1_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)
unnamed: R11.2, U2.26 (PB13/SPI2_SCK/USART3_CTS/TIM1_CH1N)
unnamed: R12.2, U2.27 (PB14/SPI2_MISO/USART3_RTS/TIM1_CH2N)
unnamed: R13.2, U2.28 (PB15/SPI2_MOSI/TIM1_CH3N)
ROTA: J15.2, J16.2, R18.1, U2.29 (USART1_CK/TIM1_CH1/MCO/PA8)
ROTB: J15.3, J16.3, R15.1, U2.30 (USART1_TX/TIM1_CH2/PA9)
ROTD: J8.2, J10.2, SW6.D, SW11.1, SW12.1, SW13.1, SW14.1, SW15.1, U2.10 (WKUP/USART2_CTS/ADC12_IN0/TIM2_CH1_ETR/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)
ROTE: D15.2 (A), SW6.E, SW15.2
ROW2: J8.3, J10.3, SW21.1, SW22.1, SW23.1, SW24.1, SW25.1, U2.11 (USART2_RTS/ADC12_IN1/TIM2_CH2/PA1)
ROW3: J7.1, J9.1, SW31.1, SW32.1, SW33.1, SW34.1, SW35.1, U2.12 (USART2_TX/ADC12_IN2/TIM2_CH3/PA2)
ROW4: J7.2, J9.2, SW41.1, SW42.1, SW43.1, SW44.1, SW45.1, U2.13 (USART2_RX/ADC12_IN3/TIM2_CH4/PA3)
ROW5: J7.3, J9.3, SW51.1, SW52.1, SW53.1, SW54.1, SW55.1, U2.14 (SPI1_NSS/USART2_CK/ADC12_IN4/PA4)
USBDN: J2.A7 (D-), J2.B7 (D-), R8.2, U1.1 (IO1)
USBDP: J2.A6 (D+), J2.B6 (D+), R5.1, R7.2, U1.3 (IO3)
Vusb: C8.1, C9.1, C11.2, C12.2, C13.2, C14.2, C15.2, C21.1, C22.1, C23.1, C24.1, C25.1, C31.2, C32.2, C33.2, C34.2, C35.2, C41.1, C42.1, C43.1, C44.1, C45.1, C51.2, C52.2, C53.2, C54.2, C55.2, CB1.1, CB2.1, CB3.1, CB4.1, CB5.1, CB6.1, CB7.1, CB8.1, J2.A4 (VBUS), J2.A9 (VBUS), J2.B4 (VBUS), J2.B9 (VBUS), J3.3, J4.2, J4.3, J5.3, J6.2, J6.3, LED11.1 (VDD), LED12.1 (VDD), LED13.1 (VDD), LED14.1 (VDD), LED15.1 (VDD), LED21.1 (VDD), LED22.1 (VDD), LED23.1 (VDD), LED24.1 (VDD), LED25.1 (VDD), LED31.1 (VDD), LED32.1 (VDD), LED33.1 (VDD), LED34.1 (VDD), LED35.1 (VDD), LED41.1 (VDD), LED42.1 (VDD), LED43.1 (VDD), LED44.1 (VDD), LED45.1 (VDD), LED51.1 (VDD), LED52.1 (VDD), LED53.1 (VDD), LED54.1 (VDD), LED55.1 (VDD), LEDB1.1 (VDD), LEDB2.1 (VDD), LEDB3.1 (VDD), LEDB4.1 (VDD), LEDB5.1 (VDD), LEDB6.1 (VDD), LEDB7.1 (VDD), LEDB8.1 (VDD), R16.1, R17.1, U1.5 (VDD), U3.3 (VI)

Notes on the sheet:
fullspeed
Only for MM32F103
Only for GD32F103
no power neg

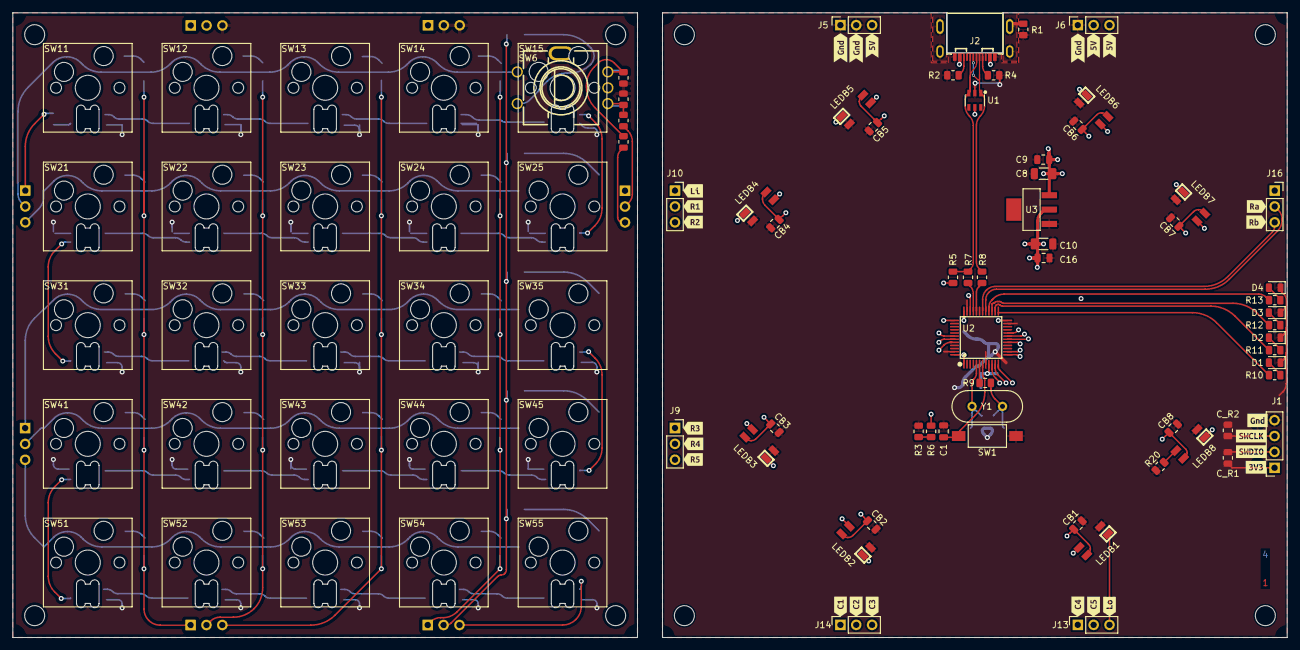
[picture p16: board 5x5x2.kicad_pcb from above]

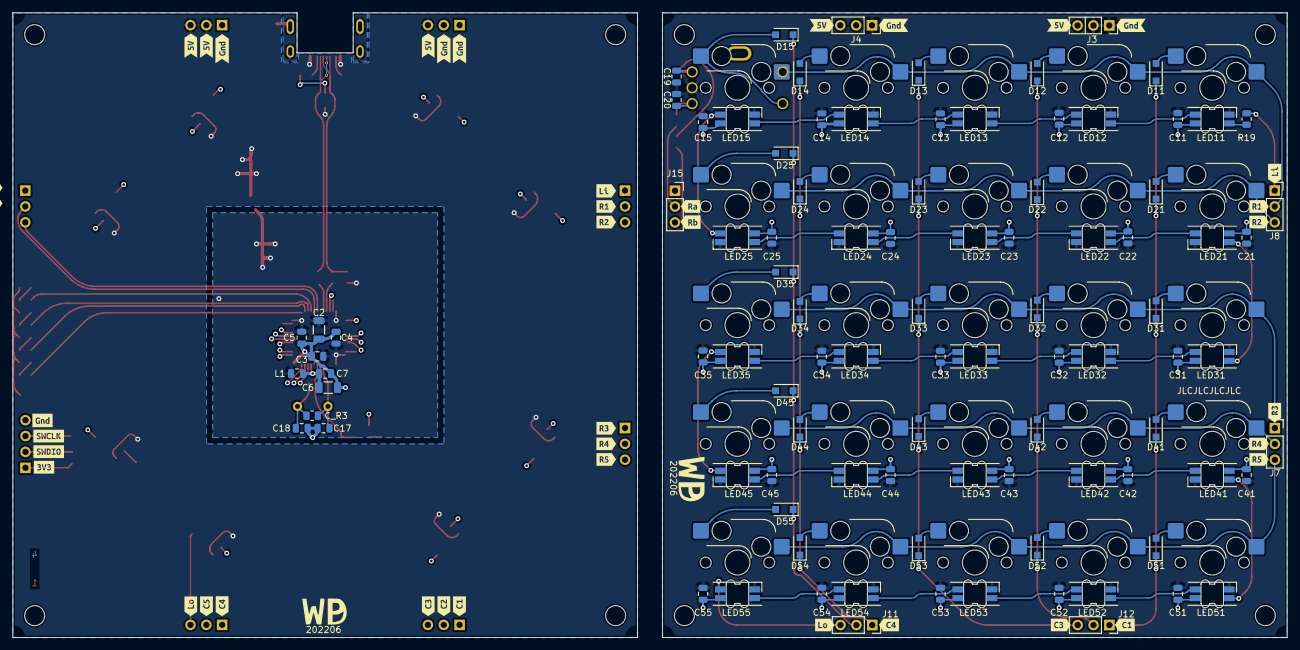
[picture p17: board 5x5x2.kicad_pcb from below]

Board: 4 copper layers, 204.0 x 100.0 mm, 244 parts (135 on the bottom side), 101 nets.

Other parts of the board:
kibuzzard-62AF6B0E: G***; kibuzzard-62AF6B0E
kibuzzard-62AF6B7C, kibuzzard-62AF6B7C#2: G***; kibuzzard-62AF6B7C
kibuzzard-62AF6B38, kibuzzard-62AF6B38#2: G***; kibuzzard-62AF6B38
kibuzzard-62AF6BA3, kibuzzard-62AF6BA3#2: G***; kibuzzard-62AF6BA3
kibuzzard-62AF6BAD, kibuzzard-62AF6BAD#2: G***; kibuzzard-62AF6BAD
kibuzzard-62AF6BF3: G***; kibuzzard-62AF6BF3
kibuzzard-62AF6D1E, kibuzzard-62AF6D1E#2: G***; kibuzzard-62AF6D1E
kibuzzard-62AF6DB1, kibuzzard-62AF6DB1#2: G***; kibuzzard-62AF6DB1
kibuzzard-62AF6E15: G***; kibuzzard-62AF6E15
kibuzzard-62AF6E21: G***; kibuzzard-62AF6E21
kibuzzard-62AF6EB6: G***; kibuzzard-62AF6EB6
kibuzzard-62AF6EDD: G***; kibuzzard-62AF6EDD
kibuzzard-62AF6F00: G***; kibuzzard-62AF6F00
kibuzzard-62AF6F11: G***; kibuzzard-62AF6F11
kibuzzard-62AF7A14, kibuzzard-62AF7A14#2: G***; kibuzzard-62AF7A14
kibuzzard-62AF7A28, kibuzzard-62AF7A28#2: G***; kibuzzard-62AF7A28
kibuzzard-62AF7A49, kibuzzard-62AF7A49#2: G***; kibuzzard-62AF7A49
kibuzzard-62AF7A56, kibuzzard-62AF7A56#2: G***; kibuzzard-62AF7A56
kibuzzard-62AF7CA9: G***; kibuzzard-62AF7CA9
kibuzzard-62AF7CCF: G***; kibuzzard-62AF7CCF
kibuzzard-62AF73B1, kibuzzard-62AF73B1#2, kibuzzard-62AF73B1#3, kibuzzard-62AF73B1#4, kibuzzard-62AF73B1#5, kibuzzard-62AF73B1#6: G***; kibuzzard-62AF73B1
kibuzzard-62AF73D1, kibuzzard-62AF73D1#2, kibuzzard-62AF73D1#3, kibuzzard-62AF73D1#4, kibuzzard-62AF73D1#5, kibuzzard-62AF73D1#6: G***; kibuzzard-62AF73D1
kibuzzard-62AF74B5, kibuzzard-62AF74B5#2: G***; kibuzzard-62AF74B5
kibuzzard-62AF74BF, kibuzzard-62AF74BF#2: G***; kibuzzard-62AF74BF
kibuzzard-62AF74C8, kibuzzard-62AF74C8#2: G***; kibuzzard-62AF74C8
kibuzzard-62AF74DA: G***; kibuzzard-62AF74DA
kibuzzard-62AF74E3: G***; kibuzzard-62AF74E3
kibuzzard-62AF74EC: G***; kibuzzard-62AF74EC
kibuzzard-62AF74F7: G***; kibuzzard-62AF74F7
kibuzzard-62AF74FE: G***; kibuzzard-62AF74FE
kibuzzard-62AF742E, kibuzzard-62AF742E#2: G***; kibuzzard-62AF742E
kibuzzard-62AF749F, kibuzzard-62AF749F#2: G***; kibuzzard-62AF749F
kibuzzard-62AF750A: G***; kibuzzard-62AF750A
kibuzzard-62AF7423, kibuzzard-62AF7423#2: G***; kibuzzard-62AF7423
kibuzzard-62AF7487, kibuzzard-62AF7487#2: G***; kibuzzard-62AF7487
kibuzzard-62AF7492, kibuzzard-62AF7492#2: G***; kibuzzard-62AF7492

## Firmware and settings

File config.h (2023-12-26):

/*
 * Copyright (c) 2015-2022 by Willem Dijkstra <wpd@xs4all.nl>.
 * All rights reserved.
 *
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
 * THIS SOFTWARE IS PROVIDED BY THE COPYRIGHT HOLDERS AND CONTRIBUTORS "AS IS" AND
 * ANY EXPRESS OR IMPLIED WARRANTIES, INCLUDING, BUT NOT LIMITED TO, THE IMPLIED
 * WARRANTIES OF MERCHANTABILITY AND FITNESS FOR A PARTICULAR PURPOSE ARE
 * DISCLAIMED. IN NO EVENT SHALL THE AUTHOR BE LIABLE FOR ANY
 * DIRECT, INDIRECT, INCIDENTAL, SPECIAL, EXEMPLARY, OR CONSEQUENTIAL DAMAGES
 * (INCLUDING, BUT NOT LIMITED TO, PROCUREMENT OF SUBSTITUTE GOODS OR SERVICES;
 * LOSS OF USE, DATA, OR PROFITS; OR BUSINESS INTERRUPTION) HOWEVER CAUSED AND
 * ON ANY THEORY OF LIABILITY, WHETHER IN CONTRACT, STRICT LIABILITY, OR TORT
 * (INCLUDING NEGLIGENCE OR OTHERWISE) ARISING IN ANY WAY OUT OF THE USE OF THIS
 * SOFTWARE, EVEN IF ADVISED OF THE POSSIBILITY OF SUCH DAMAGE.
 */

#ifndef _CONFIG_H
#define _CONFIG_H

#include "usb.h"

#define USB_GPIO              GPIOA
#define USB_RCC               RCC_GPIOA
#define USB_BV                (GPIO12)
#define SERIAL_BUF_SIZEIN     160
#define SERIAL_BUF_SIZEOUT    1024

/*
 * Matrix pinout definition:
 *
 * PA0-A4 = row driver
 * PB0-B2, B6-B7 = column reader
 *
 * COLS_DECODE is used after column GPIO reading to get a consecutive bitfield
 */

#define ROWS_NUM              5
#define ROWS_GPIO             GPIOA
#define ROWS_RCC              RCC_GPIOA
#define ROWS_BV               0b11111

#define COLS_NUM              5
#define COLS_GPIO             GPIOB
#define COLS_RCC              RCC_GPIOB
#define COLS_BV               0b11000111
#define COLS_DECODE(x)        (((x >> 3) & 0b11000) | (x & 0b111))

#define PRESSED_NUM                2

/*
 * Timeouts:
 *
 * Debounce, how long does a key need to be down to be pressed
 * Enumerate, how long may enumeration take before reset
 * Ease, how often are the rgbleds updated
 */
#define MS_DEBOUNCE           10
#define MS_ENUMERATE          5000
#define MS_EASE               1

/*
 * Number of layers possible in keymap definition
 */
#define LAYERS_NUM            3

/*
 * Number of macro keys, and max len of a macro sequence
 */
#define MACRO_MAXKEYS         12
#define MACRO_MAXLEN          32

/*
 * Number of screens to store the current desktop number for.  Should
 * be minimally the same as the number of screen you are currently
 * looking at.
 */
#define SCREENS_NUM           4

/*
 * Amount of userflash to be used to store the configuration.
 *
 * STM32 flash page size depends on the device:
 * stm32f103xx, with < 128k flash = 1k
 */
#define FLASH_PAGE_NUM        4
#define FLASH_PAGE_SIZE       0x400

#define LEDS_GPIO             GPIOB
#define LEDS_RCC              RCC_GPIOB
#define LEDS_BV               (GPIO12 | GPIO13 | GPIO14 | GPIO15)
#define LED1IO                GPIO12
#define LED2IO                GPIO13
#define LED3IO                GPIO14
#define LED4IO                GPIO15

#define AUTOMOUSE_LED_ACTIVE  (1<<2)
#define AUTOMOUSE_LED_PRESS   (1<<1)
#define MACRO_LED_ACTIVE      (1<<2)

/*
 * Backlight
 */
#define SPI_RCC               RCC_SPI1
#define SPI_GPIO_RCC          RCC_GPIOA
#define SPI_GPIO              GPIOA
#define SPI_BV                GPIO7
#define SPI_IF                SPI1
#define SPI_DATA              SPI1_DR

#define DMA_RCC               RCC_DMA1
#define DMA_IF                DMA1
#define DMA_CHANNEL           DMA_CHANNEL3
#define DMA_IRQ               NVIC_DMA1_CHANNEL3_IRQ
#define DMA_ISR_FUNCTION      dma1_channel3_isr

#define RGB_KEYS_NUM          (COLS_NUM * ROWS_NUM)
#define RGB_BACKLIGHT_NUM     8
#define RGB_ALL_NUM           (RGB_KEYS_NUM + RGB_BACKLIGHT_NUM)
#define RGB_BACKLIGHT_OFFSET  RGB_KEYS_NUM
#define RGB_BACKLIGHT_INTENS  0xff

#define PALETTE_NUM           15

/*
 * Rotary encoder
 */
#define ROT_GPIO_RCC          RCC_GPIOA
#define ROT_GPIO              GPIOA
#define ROT_TIM_RCC           RCC_TIM1
#define ROT_TIM               TIM1
#define ROT_BV                (GPIO8 | GPIO9)
#define ROT_PERIOD            65535

#endif /* _CONFIG_H */

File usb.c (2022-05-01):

/*
 * Copyright (c) 2015-2016 by Willem Dijkstra <wpd@xs4all.nl>.
 * All rights reserved.
 *
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
 * THIS SOFTWARE IS PROVIDED BY THE COPYRIGHT HOLDERS AND CONTRIBUTORS "AS IS" AND
 * ANY EXPRESS OR IMPLIED WARRANTIES, INCLUDING, BUT NOT LIMITED TO, THE IMPLIED
 * WARRANTIES OF MERCHANTABILITY AND FITNESS FOR A PARTICULAR PURPOSE ARE
 * DISCLAIMED. IN NO EVENT SHALL THE AUTHOR BE LIABLE FOR ANY
 * DIRECT, INDIRECT, INCIDENTAL, SPECIAL, EXEMPLARY, OR CONSEQUENTIAL DAMAGES
 * (INCLUDING, BUT NOT LIMITED TO, PROCUREMENT OF SUBSTITUTE GOODS OR SERVICES;
 * LOSS OF USE, DATA, OR PROFITS; OR BUSINESS INTERRUPTION) HOWEVER CAUSED AND
 * ON ANY THEORY OF LIABILITY, WHETHER IN CONTRACT, STRICT LIABILITY, OR TORT
 * (INCLUDING NEGLIGENCE OR OTHERWISE) ARISING IN ANY WAY OUT OF THE USE OF THIS
 * SOFTWARE, EVEN IF ADVISED OF THE POSSIBILITY OF SUCH DAMAGE.
 */

/*
 * USB interface
 *
 * Use the libopencm3 usb stack on top of a stm32f103 to provide usb
 * enumeration as a:
 * - boot usb keyboard
 * - boot usb mouse
 * - usb extrakey that can report <system|consumer> control/application events
 * - nkro usb keyboard
 * - a cdc/acm usb serial port
 */

#include <stdlib.h>
#include <libopencm3/cm3/nvic.h>
#include <libopencm3/cm3/systick.h>
#include <libopencm3/stm32/gpio.h>
#include <libopencm3/stm32/rcc.h>
#include <libopencm3/stm32/spi.h>
#include <libopencm3/stm32/st_usbfs.h>
#include <libopencm3/usb/cdc.h>
#include <libopencm3/usb/hid.h>
#include <libopencm3/usb/usbd.h>

#include "descriptor.h"
#include "elog.h"
#include "extrakey.h"
#include "hid.h"
#include "keyboard.h"
#include "mouse.h"
#include "usb.h"
#include "usb_keycode.h"

static usbd_device *usbd_dev;
volatile uint32_t usb_ms;
volatile uint32_t usb_ifs_enumerated;
volatile uint8_t usb_ep_keyboard_idle;
volatile uint8_t usb_ep_mouse_idle;
volatile uint8_t usb_ep_nkro_idle;
volatile uint8_t usb_ep_extrakey_idle;
volatile uint8_t usb_ep_serial_idle;

/*
 * USB hid
 *
 * Interface, endpoint and hid report definitions for the USB human interface
 * devices we provide.
 */

/*
 * Keyboard boot report, taken from USB HID 1.11 Appendix B
 *
 * Input report (8 bytes):
 * | byte | description   |
 * |------+---------------|
 * |    0 | Modifier keys |
 * |    1 | Reserved      |
 * |    2 | Keycode 1     |
 * |    3 | Keycode 2     |
 * |    4 | Keycode 3     |
 * |    5 | Keycode 4     |
 * |    6 | Keycode 5     |
 * |    7 | Keycode 6     |
 *
 * Output report (1 byte):
 * | bit | description   |
 * |-----+---------------|
 * |   0 | Num Lock      |
 * |   1 | Caps Lock     |
 * |   2 | Scroll Lock   |
 * |   3 | Compose       |
 * |   4 | Kana          |
 * | 5-7 | CONSTANT      |
 */
const uint8_t keyboard_report_descriptor[] = {
    HID_RI_USAGE_PAGE(8, 0x01),                /* Generic Desktop */
    HID_RI_USAGE(8, 0x06),                     /* Keyboard */
    HID_RI_COLLECTION(8, 0x01),                /* Application */
        HID_RI_USAGE_PAGE(8, 0x07),            /* Key Codes */
        HID_RI_USAGE_MINIMUM(8, 0xE0),         /* Keyboard Left Control */
        HID_RI_USAGE_MAXIMUM(8, 0xE7),         /* Keyboard Right GUI */
        HID_RI_LOGICAL_MINIMUM(8, 0x00),
        HID_RI_LOGICAL_MAXIMUM(8, 0x01),
        HID_RI_REPORT_COUNT(8, 0x08),
        HID_RI_REPORT_SIZE(8, 0x01),
        HID_RI_INPUT(8, HID_IOF_DATA | HID_IOF_VARIABLE | HID_IOF_ABSOLUTE),

        HID_RI_REPORT_COUNT(8, 0x01),
        HID_RI_REPORT_SIZE(8, 0x08),
        HID_RI_INPUT(8, HID_IOF_CONSTANT),     /* Reserved */

        HID_RI_USAGE_PAGE(8, 0x08),            /* LEDs */
        HID_RI_USAGE_MINIMUM(8, 0x01),         /* Num Lock */
        HID_RI_USAGE_MAXIMUM(8, 0x05),         /* Kana */
        HID_RI_REPORT_COUNT(8, 0x05),
        HID_RI_REPORT_SIZE(8, 0x01),
        HID_RI_OUTPUT(8, HID_IOF_DATA | HID_IOF_VARIABLE | HID_IOF_ABSOLUTE | HID_IOF_NON_VOLATILE),
        HID_RI_REPORT_COUNT(8, 0x01),
        HID_RI_REPORT_SIZE(8, 0x03),
        HID_RI_OUTPUT(8, HID_IOF_CONSTANT),    /* Led padding */

        HID_RI_USAGE_PAGE(8, 0x07),            /* Keyboard */
        HID_RI_USAGE_MINIMUM(8, 0x00),         /* Reserved (no event indicated) */
        HID_RI_USAGE_MAXIMUM(8, 0xFF),         /* Keyboard Application */
        HID_RI_LOGICAL_MINIMUM(8, 0x00),
        HID_RI_LOGICAL_MAXIMUM(8, 0xFF),
        HID_RI_REPORT_COUNT(8, 0x06),
        HID_RI_REPORT_SIZE(8, 0x08),
        HID_RI_INPUT(8, HID_IOF_DATA | HID_IOF_ARRAY | HID_IOF_ABSOLUTE),
    HID_RI_END_COLLECTION(0),
};

static const struct {
    struct usb_hid_descriptor hid_descriptor;
    struct {
        uint8_t bReportDescriptorType;
        uint16_t wDescriptorLength;
    } __attribute__((packed)) hid_report;
} __attribute__((packed)) keyboard_function = {
    .hid_descriptor = {
        .bLength = sizeof(keyboard_function),
        .bDescriptorType = USB_DT_HID,
        .bcdHID = 0x0111,
        .bCountryCode = 0,
        .bNumDescriptors = 1,
    },
    .hid_report = {
        .bReportDescriptorType = USB_DT_REPORT,
        .wDescriptorLength = sizeof(keyboard_report_descriptor),
    }
};

const struct usb_endpoint_descriptor keyboard_endpoint = {
    .bLength = USB_DT_ENDPOINT_SIZE,
    .bDescriptorType = USB_DT_ENDPOINT,
    .bEndpointAddress = USB_ENDPOINT_ADDR_IN(EP_KEYBOARD),
    .bmAttributes = (USB_ENDPOINT_ATTR_INTERRUPT |
                     USB_ENDPOINT_ATTR_NOSYNC |
                     USB_ENDPOINT_ATTR_DATA),
    .wMaxPacketSize = EP_SIZE_KEYBOARD,
    .bInterval = 0x0A,
};

const struct usb_interface_descriptor keyboard_iface = {
    .bLength = USB_DT_INTERFACE_SIZE,
    .bDescriptorType = USB_DT_INTERFACE,
    .bInterfaceNumber = IF_KEYBOARD,
    .bAlternateSetting = 0,
    .bNumEndpoints = 1,
    .bInterfaceClass = USB_CLASS_HID,
    .bInterfaceSubClass = ID_IS_BOOT,
    .bInterfaceProtocol = ID_IP_KEYBOARD,
    .iInterface = STRI_KEYBOARD,

    .endpoint = &keyboard_endpoint,

    .extra = &keyboard_function,
    .extralen = sizeof(keyboard_function),
};
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

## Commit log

2022-04-16 Added backlight using sk6812 leds
    The driver is in sk6812 and uses spi to communicate with a
    ledstrip. The mapping from rgb to spi format is hidden away in sk6812,
    and the backlight interactions will go to a dedicated own file.
2022-04-16 Rewrote bitbanding approach to get a tighter loop
    By separating the address and offset calculation when bitbanding, the
    compiler can now precompute the offsets, leading to a much tighter
    loop of just reading the current color bit and then writing that to
    the appropriate spi bit.
    [sk6812.c]
2022-04-17 Adjusted bit banding calculations to reflect ARM documentation
    The previous version included addition to uint32_t pointers. Addition
    of 1 then means add 4. Previously I had adjusted the defines to take
    the /4 into account, but then the calculations seem to diverge from
    what ARM specifies in their reference materials.
2022-04-18 SPI-DMA now runs contineously, while usb works on a bluepill
    Also: renamed to 5x5x2, and moved to a new git project directory.
2022-04-18 Started new schematic
    [5x5.kicad_pcb, 5x5.sch, 5x5x2.kicad_sch]
2022-04-27 Added rotary encoder
    Also added optional components when using clones.
    Rotary encoder ideas and schematic symbol came from YAEMK -- check
    license if allowed, else redraw.
    [5x5x2.kicad_sch]
2022-04-29 Schematic now has usb-c, rotarty encoder and usb tvs protection.
    [5x5x2.kicad_sch, YS-SK6812MINI-E.step]
2022-05-01 Added rotary encoder
    A rotary encoder can now be used to quickly emit events depending on
    rotation direction and current layer.
    The encoder is connected to timer 1 pins pa8 and pa9, and uses the
    quadriature decoding that is already available in the chip.
    Adjusted command.c to allow it to be set later on + adjusted flash
    load/save to be able to store the new settings.
2022-05-01 Add rotary encoder to pa8/pa9 on schematic
    [5x5x2.kicad_sch]
2022-05-14 Added initial hsv2rgb calculation for rainbow tests
    This helps determine that the leds are soldered right. Maybe include a
    rainbow in final keyboard also? That way we can check that everything
    works well at boot.
2022-05-17 Started assigning footprints
    [5x5x2.kicad_pcb, 5x5x2.kicad_sch]
2022-05-22 Added footprints, started pcb
    - used easyeda converter to get lcsc parts
    - used the kicad standard addon kbd library for the kailh socket
    - used foostans sk6812
    [5x5x2.kicad_pcb, 5x5x2.kicad_sch]
2022-05-27 Adjusted sk6812 footprint, started routing
    Adjusted sk6812 footprint from square cutout to something that is
    routable with a mill.
    The kailh sockets and leds eat up all the space between the keys. This
    means that there is not room for the micro, regulator and usb
    receptacle if we stay in a 10x10.
    Options:
    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
    [5x5x2.kicad_pcb, 5x5x2.kicad_sch]
2022-05-28 More routing
    [5x5x2.kicad_pcb, 5x5x2.kicad_sch]
2022-06-03 Routed for mcu on other pcb
    This way we can stay with 2 layers, and optionally have an additional
    pcb for just the key switches without kailh holders.
    [5x5x2.kicad_pcb, 5x5x2.kicad_sch]
2022-06-04 Added board interconnectors
    And started redoing the board interconnects -- the previous solution
    lacked symmetry and elegance (= looked like a dog's breakfast).
    [5x5x2.kicad_pcb, 5x5x2.kicad_sch]
2022-06-06 Redid board connectors, started 2nd board
    [5x5x2.kicad_pcb, 5x5x2.kicad_sch]
2022-06-18 Adjusted to 4 layer board
    - USB interface is most important, lets route that first.
    - leds interconnect will mess with everybody, so push those to the
    internal layer.
    - do away with quirky 45 degree placing
    [5x5x2.kicad_pcb, 5x5x2.kicad_sch]
2022-06-19 Routed all remaining parts.
    [5x5x2.kicad_pcb, 5x5x2.kicad_sch]
2022-06-19 Cleaned up silkscreen.
    [5x5x2.kicad_pcb]
2022-06-25 Fixed up DRC, tested footprints.
    [5x5x2.kicad_sch]
2022-06-26 Filed for production;
    - added a silk voronoi on top of control board
    - adjusted wrong footprints for background leds
    [5x5x2-part1-B_Cu.gbl, 5x5x2-part1-B_Mask.gbs, 5x5x2-part1-B_Paste.gbp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]
2022-07-10 Fix flash operations on GD32
    These devices have different internal flash and need two nops before
    flash is unlocked.
2022-07-17 Moved to actual hardware
    - easing rainbow over the backlight leds to test them at boot
    - show usb enumeration on new 4 onboard leds
    - setup regview in default make debug
    - move leds to GPIOB
    - HSV now calculated via initializer
2022-07-30 Make two halves to get gerbers for 2 and 4 layer boards
    I will delete these derivatives after this commit.
    [5x5x2-part1.kicad_pcb]
2022-07-30 Dirty solution to the farthest keys not working
    A few of my keys do not register, yet do work when the oscilloscope is
    attached. I think the termination on the column lines is not
    ideal. Currently the nops are a dirty solution, I want to try to scan
    piecemail next.
    [matrix.c]
2022-07-30 Now scan the matrix per row
    We now read the column input at the start of the matrix_scan function,
    and enable the next row at the end of this function. This allows the
    row signal to stabilise in between calls, and is more robust in the
    face of bad board layout.
    The function is more complex, as it can only build up an accurate
    picture of the keyboard after 5 consecutive calls. Update rate is
    still 20kHz, so "good enough for the girls I go out with".
    [matrix.c]
2022-07-31 Added new ease functions
    And I not really happy about it all -- the current crop have many
    magical numbers that I arrived at by trial and error.
    [config.h, rgbpixel.c]
2022-09-03 Bugfix: output at 2nd edge of sck
    This ensures that we comply closer to what the sk6812s are expecting,
    and my initial green led is now gone!
    [rgbpixel.c]
2022-09-11 Added backlight + rotation colors
    First step towards having an always on backlight + rotation that
    correlates to encoder movement
2022-12-23 Add first stab at layer movement
    The different ways to switch layers are:
    - MOVE - move to a particular layer using a keyboard switch
    - UP - move to higher layer
    - DOWN - move to lower layer
    - NEXTKEY - go to new layer for only next keypress
    - HOLD - while held goto layer, return on release
2023-01-05 Adjusted footprints for easier soldering
    - sk6812mini-e slot was too large, results in non aligned parts
    - sk6812 pads were ideal for ovenized soldering, not so much for
    handwork.
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2023-01-08 Do not adjust easing of leds when set direct via serial
    - Also: make sure rgbintensity has a reasonable default
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2023-08-25 Fix off by one bug for first backlight led
    It was set as > RGB_BACKLIGHT_OFFSET, it should be >=. This way leds
    25-32 get assigned backlight duty which is correct when viewing the
    number of led addresses as (25 + 8 - 1).
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2023-12-30 Start of enclosure in openscad
    [complete.scad, dimension.scad, plate.scad]
2023-12-31 First top plate
    This is still not quite right, but a good first start. Inter spacing
    should be 5mm, for instance.
    [complete.scad, dimension.scad, export_top_plate.scad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]
2024-01-02 Finished enclosure in OpenSCAD
    [bottom_plate.scad, complete.scad, dimension.scad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]
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
